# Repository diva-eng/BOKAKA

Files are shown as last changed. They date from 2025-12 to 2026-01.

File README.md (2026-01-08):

# Bokaka (ボカカ)

<div align="center">
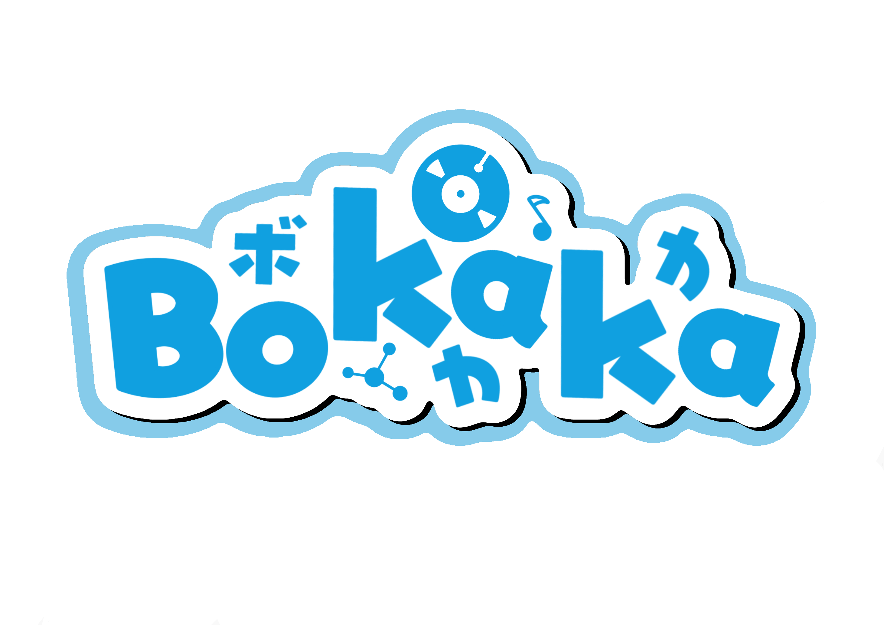
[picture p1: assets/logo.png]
Bokaka Logo
  
</div>

## Overview

Bokaka is an open-hardware, open-firmware credit-card–sized PCB distributed as a collectible at VOCALOID events (including Hatsune Miku concerts). Each unit contains a microcontroller, LEDs, a tap-to-connect interface, and local storage to record brief peer-to-peer interactions. The device visualizes interaction progress through onboard LEDs and supports synchronization with a companion website over USB.

## Key Capabilities

- Record unique, short-range interactions with other Bokaka units via a simple 1‑wire handshake over magnetic connectors.
- Persist interaction records in on‑board flash and present a visual progress/connection meter using 34 animation LEDs.
- Connect to a host computer over USB (WebUSB compatible) to claim the device, attach personal information, and upload interaction data to a companion website.
- Per-device security with unique device ID and locally stored HMAC-SHA256 secret keys.

## Hardware Summary

- Form factor: Credit-card–sized PCB
- Microcontroller: STM32L053R8 (low power, USB, unique device ID)
- Power:
  - Primary: CR2450 coin cell for sustained standalone operation
  - Optional: USB‑C for data and power
- Communication:
  - 2× 3-wire magnetic connectors with 1-wire open-drain Bokaka protocol
  - USB CDC (WebUSB compatible) for host connectivity
- Peripherals:
  - LED driver: IS31FL3236A (36-channel LED driver)
  - LEDs: 34 animation LEDs, 1 user status LED, 1 debug LED (36 total)
  - Single status button
  - Buzzer for simple sound feedback

## Functional Description

When two Bokaka units are tapped together via their magnetic connectors, they perform a one‑wire open-drain handshake and exchange unique identifiers. Each successful exchange is recorded to on‑board flash memory with CRC32 integrity checking. The device uses the IS31FL3236A LED driver to control 34 animation LEDs that display connection status, progress animations, and cumulative "connection meter" patterns. Two additional LEDs (user status and debug) provide system feedback. When connected to a host computer via USB, the user may:

1. Claim ownership of the card.
2. Attach optional personal metadata to the device.
3. Synchronize recorded interactions with a companion website to visualize social graphs (WebUSB compatible, no drivers required).

## Development and Firmware

- Firmware: PlatformIO with the Arduino framework targeting the STM32L053R8, with platform abstraction layer for future STM32CubeIDE migration.
- PCB design: KiCad (open hardware files included).
- Security: Per-device HMAC-SHA256 with rotating key versions, unique device IDs.
- Storage: Internal flash with EEPROM emulation, CRC32 integrity checking, optimized delayed writes for flash wear management.
- Goals: Maintain low power consumption for CR2450 coin‑cell operation, robust flash management for interaction logs, and a simple, extensible 1-wire protocol for tap interactions.

## Project Structure (typical)

- hardware/ — KiCad project files and manufacturing outputs
- firmware/ — PlatformIO project, source code, and build scripts
- docs/ — Design notes, protocol specification, and user documentation
- tools/ — Utility scripts for flashing, testing, and data conversion

## Usage

- Standalone: Power via CR2450 coin cell and perform tap interactions with other units via magnetic connectors.
- Host mode: Connect via USB‑C to a host (WebUSB compatible) to perform claiming, metadata attachment, and data synchronization.
- Interaction protocol: 1‑wire open-drain handshake using the magnetic connector interface; exchanged identifiers are stored locally with CRC32 verification.

## Contribution & Licensing

Contributions are welcome. See [CONTRIBUTING.md](CONTRIBUTING.md) for process and coding standards. Utility scripts (including the provisioning helper) live in `utils/` — see [utils/README.md](utils/README.md) for usage. The project is released under an open hardware / open source license (see LICENSE).

## Contacts & Resources

Refer to the repository for detailed build instructions, protocol documentation, and firmware API references.

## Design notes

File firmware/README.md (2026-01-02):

# Bokaka Firmware

**Bokaka** is an interactive smart PCB card designed to connect VOCALOID fans through simple, meaningful physical interactions.  
Powered by a low‑energy microcontroller and magnetic tap‑to‑link interface, Bokaka creates a shared experience that blends hardware, community, and creativity.

---

## 🌱 What is Bokaka?

Bokaka is a pocket‑sized device that allows fans to exchange identity tokens simply by tapping their cards together.  
Each successful interaction lights up part of an LED pattern on the card—forming leeks, Miku‑themed shapes, or rare animations as you meet more fans.

- Meet someone → Tap cards  
- Cards exchange secure IDs  
- Your LED pattern grows  
- Reach milestones → unlock animations  
- Sync to the website → view your connection graph

Bokaka turns fan encounters into a visual memory you can carry.

---

## ✨ Features

| Feature | Description |
|---|---|
| **🔵 Tap‑to‑Connect** | Magnetic pogo‑pin contact pads with stable one‑wire handshake protocol |
| **🟢 LED Status Display** | Energy‑efficient LEDs showing connection status and role |
| **🟣 WebUSB Support** | No drivers required - configure and sync directly in your browser |
| **🛡 Per‑Device Security** | Unique device ID with locally stored HMAC secret key |
| **🌐 Connection Graph** | Sync to companion site for worldwide fan visualization |

---

## 🧩 Technical Overview

| Component | Detail |
|---|---|
| MCU | STM32L053R8 with unique ID + low‑power modes |
| Interface | Magnetic pogo‑pin contact pads (1-wire open-drain) |
| Security | Per‑device HMAC-SHA256 with rotating key versions |
| Connectivity | USB CDC (WebUSB compatible) |
| Storage | Internal flash with CRC32 integrity checking |
| Framework | Arduino (via PlatformIO) with platform abstraction layer |

---

## 📁 Project Structure

```
firmware/
├── include/                    # Header files
│   ├── platform_*.h            # Platform abstraction interfaces
│   ├── storage.h               # Persistent storage interface
│   ├── tap_link.h              # Tap link protocol
│   ├── usb_serial.h            # USB command handler
│   └── status_display.h        # LED status display
├── src/                        # Source files
│   ├── main.cpp                # Main application
│   ├── platform_*_arduino.cpp  # Arduino platform implementations
│   ├── storage.cpp             # Storage implementation
│   ├── tap_link.cpp            # Tap link protocol
│   └── status_display.cpp      # LED status display
├── lib/                        # Libraries
│   └── crypto_config/          # mbedTLS configuration
├── docs/                       # Documentation
│   ├── FLASH_LIFETIME_ANALYSIS.md
│   ├── TAP_LINK_TIMING.md
│   ├── TAP_INTERFACE_WIRING.md
│   └── STATUS_DISPLAY.md
├── utils/                      # Utility scripts
│   ├── provision.py            # Key provisioning tool
│   └── serial_test.py          # Serial testing utility
├── platformio.ini              # Build configuration
└── PLATFORM_ABSTRACTION.md     # Platform abstraction documentation
```

---

## 🔧 Building

### Prerequisites

- [PlatformIO](https://platformio.org/) (VSCode extension or CLI)
- ST-Link programmer/debugger

### Build Commands

```bash
# Build for production
pio run -e nucleo_l053r8

# Build with test commands enabled
pio run -e dev

# Upload to device
pio run -e nucleo_l053r8 -t upload

# Monitor serial output
pio device monitor
```

### Build Environments

| Environment | Description |
|---|---|
| `nucleo_l053r8` | Production build |
| `dev` | Development build with `ENABLE_TEST_COMMANDS` |

---

## ⚠️ Flash Memory Wear Management

The firmware uses EEPROM emulation on STM32 flash memory. **Flash wear is a critical consideration:**

- **Flash Endurance**: STM32L0 flash has ~10,000 erase/write cycles per page
- **Write Strategy**: 
  - Regular operations use a 30-second delayed write to batch changes
  - Critical operations (like key provisioning) write immediately but occur rarely
  - Optimized partial writes for tap count and links (8-18 bytes vs 896 bytes)

**Lifetime Estimates** (for <100 links/event, multiple events/year):
- **Realistic case**: ~40 years at 10 events/year
- **Worst case**: ~10 years if writes aren't batched
- **With external flash**: 400+ years (recommended for production)

📊 **See [docs/FLASH_LIFETIME_ANALYSIS.md](docs/FLASH_LIFETIME_ANALYSIS.md) for detailed calculations.**

---

## 📖 Documentation

| Document | Description |
|---|---|
| [PLATFORM_ABSTRACTION.md](PLATFORM_ABSTRACTION.md) | Platform abstraction layer design and migration guide |
| [MIGRATION_PLAN.md](MIGRATION_PLAN.md) | Step-by-step STM32CubeIDE migration plan |
| [docs/REFACTORING_GUIDE.md](docs/REFACTORING_GUIDE.md) | Code refactoring opportunities for testability |
| [docs/TAP_LINK_TIMING.md](docs/TAP_LINK_TIMING.md) | Tap link protocol timing diagrams |
| [docs/TAP_INTERFACE_WIRING.md](docs/TAP_INTERFACE_WIRING.md) | Hardware wiring guide for two-board testing |
| [docs/STATUS_DISPLAY.md](docs/STATUS_DISPLAY.md) | LED status patterns and configuration |
| [docs/FLASH_LIFETIME_ANALYSIS.md](docs/FLASH_LIFETIME_ANALYSIS.md) | Flash wear analysis and recommendations |

---

## ❤️ Community

Bokaka is made for fans who want to share a moment of connection—whether at concerts, events, or anywhere creativity brings people together.

If you'd like to contribute, discuss features, or share ideas, feel free to open issues or PRs!

---

## 📄 License

MIT License

Copyright (c) 2025 Diva Engineering

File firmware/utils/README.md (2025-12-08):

```markdown
**Provision Script**: Brief usage

- **Purpose**: `provision.py` provisions a device over USB serial by sending `HELLO`, provisioning a generated 32-byte secret via `PROVISION_KEY`, validating via `SIGN_STATE`, and storing keys locally.

- **Run (PowerShell)**:

  ```powershell
  # Watch for new COM ports and provision automatically (interactive confirmation enabled)
  python .\utils\provision.py

  # Watch a specific port and provision whenever it appears
  python .\utils\provision.py --port COM3

  # Provision once and exit
  python .\utils\provision.py --port COM3 --once

  # Skip signature validation step (device will not be asked to sign state)
  python .\utils\provision.py --no-validate

  # Emulate a device locally (no hardware required)
  python .\utils\provision.py --emulate

  # Emulate with a longer artificial response delay so the UI updates are visible
  python .\utils\provision.py --emulate --emulate-delay 0.8

  # Skip interactive confirmation prompts (auto-accept provisioning)
  python .\utils\provision.py --emulate --no-confirm

  # Use a master key (hex) to derive device keys deterministically
  python .\utils\provision.py --master-key-hex ABCDEF0123...    # pass 32-byte master key as hex

  # Or load a PEM private key to sign provisioned secrets
  python .\utils\provision.py --master-key-pem path/to/key.pem
  ```

- **Dependencies**:
  - `pyserial` — install with `pip install pyserial`.
  - `rich` — optional but recommended for the improved in-place UI (Device / Status / Log panels, colored output, spinner and elapsed timer). Install with `pip install rich`.
  - `cryptography` — optional; required when using `--master-key-hex` or `--master-key-pem` to sign provisioned secrets. Install with `pip install cryptography`.

- **New / notable features**:
  - In-place UI (uses `rich` when available): separate Device / Status / Log panels, colored log output, auto-scroll to latest lines, and a small spinner + elapsed timer in the status bar.
  - Emulation improvements: `--emulate-delay` controls artificial response delay so UI updates are visible.
  - Interactive confirmation: the script prompts before provisioning a newly-detected device (shows device info from `HELLO`) and temporarily suspends the live UI to accept keyboard input.
  - Non-interactive mode: pass `--no-confirm` to skip confirmation prompts and accept provisioning automatically (useful for CI or batch runs).

- **Output**: keys are saved to `utils/provision_keys.json` by default; use `--out <path>` to change the file.

If you want me to add support for selecting VID/PID, filtering candidate ports, or changing colors/layout, I can extend the script.
```

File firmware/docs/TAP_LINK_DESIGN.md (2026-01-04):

# Tap Link Design

## Overview

TapLink implements device-to-device communication over a single GPIO wire using an open-drain protocol. It handles connection detection, role negotiation, and bidirectional command exchange.

## Operation Modes

### Eval Board Mode (EVAL_BOARD_TEST)

USB-powered continuous monitoring for development:
- Sends periodic presence pulses
- Automatic role negotiation on connection
- Command protocol for peer communication

### Battery Mode (default)

CR2032-powered with sleep/wake:
- MCU sleeps until tap wake-up interrupt
- Validates connection stability
- Minimal power consumption

## Architecture

```
┌─────────────────────────────────────────────────────────────┐
│                         Application                         │
├─────────────────────────────────────────────────────────────┤
│         ITapLink / ITapLinkEval / ITapLinkBattery           │
├─────────────────────────────────────────────────────────────┤
│                           TapLink                           │
│  ┌─────────────┐  ┌──────────────┐  ┌────────────────────┐  │
│  │ Detection   │  │ Negotiation  │  │ Command Protocol   │  │
│  │ State       │  │ (UID bits)   │  │ (Master/Slave)     │  │
│  └─────────────┘  └──────────────┘  └────────────────────┘  │
├─────────────────────────────────────────────────────────────┤
│                         IOneWireHal                         │
│                 (tap_link_hal_arduino.cpp)                  │
├─────────────────────────────────────────────────────────────┤
│                      Platform GPIO HAL                      │
└─────────────────────────────────────────────────────────────┘
```

## Electrical Interface

### Open-Drain Protocol

```
          Device A                    Device B
             │                           │
   ┌─────────┴─────────┐       ┌─────────┴─────────┐
   │ GPIO (Open-Drain) │───────│ GPIO (Open-Drain) │
   │ + Internal Pull-up│       │ + Internal Pull-up│
   └───────────────────┘       └───────────────────┘
```

- Idle state: HIGH (via internal pull-ups)
- Either device can pull LOW
- Wired-AND: line is HIGH only if both devices release
- No bus contention possible

### GPIO Configuration

| Mode | Config | Description |
|---|---|---|
| Release | INPUT_PULLUP | High-Z with pull-up (line goes HIGH) |
| Drive LOW | OUTPUT + LOW | Actively pulls line to ground |

## Detection State Machine (Eval Mode)

```
┌──────────────┐
│ NoConnection │◄────────────────────────────────┐
└──────┬───────┘                                 │
       │ Line goes LOW (peer pulse)              │
       ▼                                         │
┌──────────────┐                                 │
│  Detecting   │                                 │
└──────┬───────┘                                 │
       │ Line goes HIGH or debounce timeout      │
       ▼                                         │
┌──────────────┐                                 │
│ Negotiating  │                                 │
└──────┬───────┘                                 │
       │ Role determined                         │
       ▼                                         │
┌──────────────┐                                 │
│  Connected   │─────────────────────────────────┘
└──────────────┘   Timeout or repeated failures
```

## Presence Pulse Detection

When not connected, both devices send periodic presence pulses:

```
Timing:
- Pulse width: 2ms (PRESENCE_PULSE_US)
- Pulse interval: 50ms (PULSE_INTERVAL_US)
- Debounce time: 5ms (DEBOUNCE_TIME_US)

       Device A sends pulse                  Device B detects
              │                                    │
    HIGH ─────┴────┐          ┌────────────────────┴───────── HIGH
                   │          │
    LOW            └──────────┘
                   ◄──────────► 2ms
```

## Role Negotiation Protocol

### Synchronization Handshake

Both devices must start bit exchange simultaneously:

```
1. Release line, wait for HIGH
2. Send 10ms sync pulse
3. Wait for line HIGH
4. Wait for peer's sync pulse (up to 50ms)
5. Wait for peer's pulse to complete
6. 5ms delay
7. Send second 10ms sync pulse
8. Wait for line HIGH
9. 5ms final alignment delay
10. Begin bit exchange
```

This achieves ~1-2ms synchronization accuracy.

### UID Bit Exchange

Higher UID becomes Master. First 32 bits of device UID are compared:

```
Timing per bit:
- Drive period: 5ms (BIT_DRIVE_US)
- Sample point: 2.5ms (BIT_SAMPLE_US)
- Recovery: 2ms (BIT_RECOVERY_US)

For each bit position (MSB first):
1. Drive line based on my bit (0 = LOW, 1 = release)
2. Wait 2.5ms (sample point)
3. Sample line 3 times with majority voting
4. Continue driving until 5ms total
5. Release line
6. 2ms recovery
7. Next bit

Decision logic:
- If I sent '1' (released) but line is LOW → peer sent '0' → I am MASTER
- If bits match, continue to next bit
- After 32 bits: use random tie-breaker, then UID sum parity
```

### Why 5ms Drive Period

The long drive period (5ms) with mid-point sampling (2.5ms) ensures reliable reading even with ~2ms sync error between devices. Both devices are guaranteed to be in their drive phase when sampling occurs.

## Command Protocol (Connected State)

### Packet Format

```
START pulse (5ms) → Turnaround (2ms) → Command byte → Turnaround (2ms) → Response byte
```

### Bit Timing

Same as negotiation: 5ms drive, 2.5ms sample, 2ms recovery.

### Commands

| Code | Command | Description |
|---|---|---|
| 0x01 | CHECK_READY | Master polls slave availability |
| 0x02 | REQUEST_ID | Master requests slave's UID |
| 0x03 | SEND_ID | Master sends its UID to slave |

### Responses

| Code | Response | Description |
|---|---|---|
| 0x06 | ACK | Command successful |
| 0x15 | NAK | Command rejected |

### ID Exchange Sequence

```
Master                              Slave
  │                                   │
  ├── START + REQUEST_ID ───────────►│
  │                                   │
  │◄───────────── ACK ────────────────┤
  │◄──────────── UID (12 bytes) ──────┤
  │                                   │
  ├── START + SEND_ID ───────────────►│
  ├── UID (12 bytes) ────────────────►│
  │                                   │
  │◄───────────── ACK ────────────────┤
  │                                   │
```

### Disconnect Detection

**Master side:**
- Tracks consecutive command failures
- After 3 failures (MAX_COMMAND_FAILURES): transition to NoConnection
- Invalid responses (0xFF from floating line) count as failures

**Slave side:**
- Tracks time since last command received
- After 2 seconds (SLAVE_IDLE_TIMEOUT_US): transition to NoConnection

## Timing Constants

| Constant | Value | Purpose |
|---|---|---|
| DEBOUNCE_TIME_US | 5,000 | Connection detection debounce |
| PRESENCE_PULSE_US | 2,000 | Presence pulse width |
| PULSE_INTERVAL_US | 50,000 | Time between presence pulses |
| BIT_DRIVE_US | 5,000 | Bit drive duration |
| BIT_SAMPLE_US | 2,500 | Sample point within bit slot |
| BIT_RECOVERY_US | 2,000 | Recovery between bits |
| SYNC_PULSE_US | 10,000 | Sync handshake pulse |
| SYNC_WAIT_US | 5,000 | Sync alignment delay |
| CMD_START_PULSE_US | 5,000 | Command start pulse |
| CMD_TURNAROUND_US | 2,000 | Send/receive turnaround |
| CMD_TIMEOUT_US | 100,000 | Command response timeout |
| SLAVE_IDLE_TIMEOUT_US | 2,000,000 | Slave disconnect timeout |

## Battery Mode State Machine

```
┌──────────────┐
│   Sleeping   │◄────────────────┐
└──────┬───────┘                 │
       │ Wake-up interrupt       │
       ▼                         │
┌──────────────┐                 │
│    Waking    │─────────────────┤ Connection not stable
└──────┬───────┘                 │
       │ Validation complete     │
       ▼                         │
┌──────────────┐                 │
│  Connected   │                 │
└──────┬───────┘                 │
       │ Disconnect detected     │
       ▼                         │
┌──────────────┐                 │
│ Disconnected │─────────────────┘
└──────────────┘
```

### Connection Validation

Multiple line readings confirm stable connection:

```cpp
bool readings[5];
for (int i = 0; i < 5; i++) {
    readings[i] = _hal->readLine();
    delayMicros(100);
}
// Connection valid if all readings are consistent
```

## HAL Interface

```cpp
struct IOneWireHal {
    virtual bool readLine() = 0;              // true = HIGH
    virtual void driveLow(bool enable) = 0;   // true = pull LOW
    virtual uint32_t micros() = 0;
    virtual void delayMicros(uint32_t us) = 0;
};
```

Platform implementation in `tap_link_hal_arduino.cpp` maps to GPIO and timing HAL.

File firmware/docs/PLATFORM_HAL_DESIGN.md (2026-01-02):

# Platform Hardware Abstraction Layer Design

## Overview

The platform HAL provides hardware-independent interfaces for GPIO, timing, serial, storage, and device identification. This enables the same application code to run on Arduino/PlatformIO and STM32CubeIDE with minimal changes.

## Architecture

```
┌─────────────────────────────────────────────────────────────┐
│                      Application                             │
├─────────────────────────────────────────────────────────────┤
│                    Platform Interfaces                       │
│  ┌─────────┐ ┌─────────┐ ┌──────────┐ ┌─────────┐ ┌───────┐ │
│  │  GPIO   │ │ Timing  │ │ Serial   │ │ Storage │ │Device │ │
│  └────┬────┘ └────┬────┘ └────┬─────┘ └────┬────┘ └───┬───┘ │
├───────┼──────────┼──────────┼───────────┼──────────┼───────┤
│       │          │          │           │          │        │
│  ┌────┴────┐┌────┴────┐┌────┴─────┐┌────┴────┐┌────┴────┐  │
│  │ Arduino ││ Arduino ││ Arduino  ││ Arduino ││ Arduino │  │
│  │  GPIO   ││ millis  ││ Serial   ││ EEPROM  ││STM32 HAL│  │
│  └─────────┘└─────────┘└──────────┘└─────────┘└─────────┘  │
│                                                              │
│  ┌─────────┐┌─────────┐┌──────────┐┌─────────┐┌─────────┐  │
│  │STM32 HAL││STM32 HAL││ STM32 USB││STM32 HAL││STM32 HAL│  │
│  │  GPIO   ││  TIM    ││   CDC    ││ FLASH   ││  UID    │  │
│  └─────────┘└─────────┘└──────────┘└─────────┘└─────────┘  │
└─────────────────────────────────────────────────────────────┘
```

## GPIO Interface

**Header:** `include/platform_gpio.h`  
**Arduino impl:** `src/platform_gpio_arduino.cpp`

### Pin Modes

```cpp
typedef enum {
    PLATFORM_GPIO_MODE_INPUT,        // High-impedance input
    PLATFORM_GPIO_MODE_INPUT_PULLUP, // Input with internal pull-up
    PLATFORM_GPIO_MODE_OUTPUT,       // Push-pull output
    PLATFORM_GPIO_MODE_OUTPUT_OD     // Open-drain output
} platform_gpio_mode_t;
```

### Functions

```cpp
void platform_gpio_pin_mode(uint32_t pin, platform_gpio_mode_t mode);
bool platform_gpio_read(uint32_t pin);
void platform_gpio_write(uint32_t pin, platform_gpio_state_t state);
```

### Arduino Implementation Notes

- `PLATFORM_GPIO_MODE_OUTPUT_OD` maps to standard OUTPUT mode
- True open-drain behavior depends on hardware capability
- Pin identifiers use Arduino constants (PA5, PA6, etc.)

### STM32 HAL Migration

```cpp
// Arduino
pinMode(pin, INPUT_PULLUP);
digitalRead(pin);
digitalWrite(pin, HIGH);

// STM32 HAL
GPIO_InitTypeDef init = {.Mode = GPIO_MODE_INPUT, .Pull = GPIO_PULLUP};
HAL_GPIO_Init(GPIOx, &init);
HAL_GPIO_ReadPin(GPIOx, pin);
HAL_GPIO_WritePin(GPIOx, pin, GPIO_PIN_SET);
```

## Timing Interface

**Header:** `include/platform_timing.h`  
**Arduino impl:** `src/platform_timing_arduino.cpp`

### Functions

```cpp
void platform_timing_init();           // Initialize timing system
uint32_t platform_millis();            // Milliseconds since boot (wraps ~49 days)
uint32_t platform_micros();            // Microseconds since boot (wraps ~71 min)
void platform_delay_ms(uint32_t ms);   // Blocking millisecond delay
void platform_delay_us(uint32_t us);   // Blocking microsecond delay
```

### Arduino Implementation

Direct wrapper around Arduino functions:
- `millis()`, `micros()`, `delay()`, `delayMicroseconds()`
- `platform_timing_init()` is a no-op (Arduino auto-initializes)

### STM32 HAL Migration

```cpp
// Uses SysTick or dedicated timer
HAL_GetTick();           // 1ms resolution
TIM->CNT;                // Microsecond counter from hardware timer
HAL_Delay(ms);           // Blocking delay
// Custom DWT cycle counter for microsecond delays
```

### Overflow Handling

The application handles timer overflow correctly:

```cpp
uint32_t elapsedMicros(uint32_t startTime) {
    uint32_t now = platform_micros();
    if (now >= startTime) {
        return now - startTime;
    } else {
        return (UINT32_MAX - startTime) + now + 1;
    }
}
```

## Serial Interface

**Header:** `include/platform_serial.h`  
**Arduino impl:** `src/platform_serial_arduino.cpp`

### Functions

```cpp
void platform_serial_begin(uint32_t baud);   // Initialize (baud ignored for USB)
int platform_serial_available();             // Bytes available to read
int platform_serial_read();                  // Read byte (-1 if none)
void platform_serial_print(const char* str); // Print string
void platform_serial_print(int num);         // Print integer
void platform_serial_print(uint32_t num);    // Print unsigned
void platform_serial_print_hex(uint8_t byte);// Print hex byte
void platform_serial_println(const char* str);
void platform_serial_flush();                // Wait for TX complete
```

### Arduino Implementation

Direct wrapper around `Serial` object (USB CDC on STM32).

### STM32 HAL Migration

```cpp
// USB CDC requires CDC_Transmit_FS() and CDC_Receive_FS()
// Or UART with HAL_UART_Transmit/Receive
CDC_Transmit_FS((uint8_t*)str, strlen(str));
```

## Storage Interface

**Header:** `include/platform_storage.h`  
**Arduino impl:** `src/platform_storage_arduino.cpp`

### Functions

```cpp
bool platform_storage_begin(size_t size);      // Initialize storage
uint8_t platform_storage_read(size_t address); // Read byte
void platform_storage_write(size_t address, uint8_t value);
bool platform_storage_commit();                // Flush writes
```

### Arduino Implementation Notes

- Uses STM32 Arduino EEPROM library
- `EEPROM.begin()` doesn't take size parameter on STM32
- Size is tracked internally for bounds checking
- `commit()` may be no-op depending on core implementation

### STM32 HAL Migration

EEPROM emulation in flash requires:
- Page erase before write
- Virtual address mapping
- Wear leveling (optional)

```cpp
// STM32 HAL flash operations
HAL_FLASHEx_DATAEEPROM_Unlock();
HAL_FLASHEx_DATAEEPROM_Program(FLASH_TYPEPROGRAMDATA_BYTE, addr, data);
HAL_FLASHEx_DATAEEPROM_Lock();
```

## Device Identity Interface

**Header:** `include/platform_device.h`  
**Arduino impl:** `src/platform_device_arduino.cpp`

### Functions

```cpp
void platform_get_device_uid(uint8_t out[PLATFORM_DEVICE_UID_SIZE]);
```

Returns 12-byte (96-bit) unique device ID.

### STM32 Implementation

STM32L0 UID is stored at fixed memory addresses, accessible via HAL:

```cpp
uint32_t w0 = HAL_GetUIDw0();
uint32_t w1 = HAL_GetUIDw1();
uint32_t w2 = HAL_GetUIDw2();
```

Bytes are extracted in big-endian order for consistent ID comparison across devices.

### Memory Layout

```
UID Word 0 (address 0x1FF80050): out[0..3]
UID Word 1 (address 0x1FF80054): out[4..7]
UID Word 2 (address 0x1FF80064): out[8..11]
```

## TapLink HAL

**Header:** `include/tap_link_hal.h`  
**Arduino impl:** `src/tap_link_hal_arduino.cpp`

### Interface

```cpp
struct IOneWireHal {
    virtual bool readLine() = 0;              // Read physical line state
    virtual void driveLow(bool enableLow) = 0;// Control line driver
    virtual uint32_t micros() = 0;            // Get microseconds
    virtual void delayMicros(uint32_t us) = 0;// Blocking delay
};
```

### Arduino Implementation

```cpp
class OneWireHalArduino : public IOneWireHal {
    uint32_t _pin;
public:
    bool readLine() override {
        return platform_gpio_read(_pin);
    }
    
    void driveLow(bool enableLow) override {
        if (enableLow) {
            platform_gpio_pin_mode(_pin, PLATFORM_GPIO_MODE_OUTPUT);
            platform_gpio_write(_pin, PLATFORM_GPIO_LOW);
        } else {
            platform_gpio_pin_mode(_pin, PLATFORM_GPIO_MODE_INPUT_PULLUP);
        }
    }
    
    uint32_t micros() override { return platform_micros(); }
    void delayMicros(uint32_t us) override { platform_delay_us(us); }
};
```

## Board Configuration

**Header:** `include/board_config.h`

Pin definitions with defaults, overridable via build flags:

```cpp
#ifndef STATUS_LED0_PIN
#define STATUS_LED0_PIN PA5   // D13 on Nucleo
#endif

#ifndef STATUS_LED1_PIN
#define STATUS_LED1_PIN PA6   // D12 on Nucleo
#endif

#ifndef TAP_LINK_PIN
#define TAP_LINK_PIN PA9      // D8 on Nucleo
#endif
```

Override in `platformio.ini`:
```ini
build_flags = -DSTATUS_LED0_PIN=PB0
```

## Migration Checklist

To port to STM32CubeIDE:

1. **GPIO:** Replace pinMode/digitalRead/Write with HAL_GPIO_*
2. **Timing:** Configure SysTick, add microsecond timer
3. **Serial:** Implement USB CDC or UART wrapper
4. **Storage:** Implement flash EEPROM emulation
5. **Device:** Direct memory access for UID (already uses HAL)
6. **Sleep:** Add HAL_PWR_EnterSLEEPMode with GPIO wake-up

See `PLATFORM_ABSTRACTION.md` and `MIGRATION_PLAN.md` for detailed migration steps.

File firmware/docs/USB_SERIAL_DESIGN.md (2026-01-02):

# USB Serial Command Handler Design

## Overview

The USB serial module provides a JSON-based command interface over USB CDC for device management, debugging, and provisioning.

## Architecture

```
┌─────────────────────────────────────────────────────────────┐
│                    Host PC (Python/etc)                      │
├─────────────────────────────────────────────────────────────┤
│                      USB CDC Serial                          │
├─────────────────────────────────────────────────────────────┤
│                  UsbCommandHandler                           │
│  ┌─────────────┐  ┌──────────────┐  ┌────────────────────┐  │
│  │ Line Buffer │  │ Command Parse│  │ JSON Response      │  │
│  └─────────────┘  └──────────────┘  └────────────────────┘  │
├─────────────────────────────────────────────────────────────┤
│                  Platform Serial HAL                         │
│              (platform_serial_arduino.cpp)                   │
├─────────────────────────────────────────────────────────────┤
│                   Arduino Serial (USB CDC)                   │
└─────────────────────────────────────────────────────────────┘
```

## Initialization

### USB CDC Enumeration

STM32 USB CDC requires time to enumerate after power-on:

```cpp
void begin(unsigned long baud) {
    platform_serial_begin(baud);
    platform_delay_ms(500);        // Wait for USB enumeration
    
    // Flush stale data from input buffer
    uint32_t flushStart = platform_millis();
    while (platform_serial_available() > 0 && 
           (platform_millis() - flushStart < 100)) {
        platform_serial_read();
        platform_delay_ms(1);
    }
    
    platform_delay_ms(100);        // Final settling time
}
```

Without this flush, the first command can be corrupted by initialization noise.

## Command Protocol

### Line Format

- Commands are newline-terminated (`\n` or `\r\n`)
- Case-insensitive (converted to uppercase internally)
- Arguments separated by spaces

### Response Format

All responses are JSON objects with an `event` field:

```json
{"event":"hello","device_id":"...","fw":"1.0.0"}
{"event":"state","totalTapCount":42,"linkCount":5}
{"event":"error","msg":"unknown command: FOO"}
```

## Commands

### HELLO

Returns device identification and firmware info.

```
Request:  HELLO
Response: {"event":"hello","device_id":"<24-char hex>","fw":"1.0.0","build":"2026-01-03T12:00:00Z","hash":"abc123"}
```

### GET_STATE

Returns current tap statistics.

```
Request:  GET_STATE
Response: {"event":"state","totalTapCount":42,"linkCount":5}
```

### CLEAR / RESET_TAPS

Clears all links and tap count (preserves selfId and secret key).

```
Request:  CLEAR
Response: {"event":"ack","cmd":"CLEAR"}
```

Note: ACK is sent before the blocking EEPROM write to prevent serial timeout.

### DUMP [offset] [count]

Returns stored peer links with pagination.

```
Request:  DUMP 0 10
Response: {"event":"links","offset":0,"count":3,"items":[{"peer":"A1B2C3..."},{"peer":"D4E5F6..."}]}
```

Default: offset=0, count=10

### PROVISION_KEY version key_hex

Provisions a 32-byte secret key for HMAC signing.

```
Request:  PROVISION_KEY 1 <64-char hex key>
Response: {"event":"ack","cmd":"PROVISION_KEY","keyVersion":1}
```

Note: ACK sent before EEPROM write. Key is saved immediately (no delay).

### SIGN_STATE nonce_hex

Signs current state with HMAC-SHA256 for server verification.

```
Request:  SIGN_STATE <2-64 char hex nonce>
Response: {"event":"SIGNED_STATE","device_id":"...","nonce":"...","totalTapCount":42,"linkCount":5,"keyVersion":1,"hmac":"<64-char hex>"}
```

HMAC message structure:
```
selfId (12 bytes) + nonce (N bytes) + totalTapCount (4 LE) + linkCount (2 LE) + [peerId × linkCount]
```

### GET_KEY (test builds only)

Returns the stored secret key. Only available when `ENABLE_TEST_COMMANDS` is defined.

```
Request:  GET_KEY
Response: {"event":"key","keyVersion":1,"key":"<64-char hex>"}
```

## Input Processing

### Line Buffer

```cpp
static constexpr size_t CMD_BUF_SIZE = 128;
char _buf[CMD_BUF_SIZE];
size_t _len = 0;
```

Characters are accumulated until newline. Buffer overflow discards the line.

### Polling Model

```cpp
void poll(IStorage& storage) {
    while (platform_serial_available() > 0) {
        int c = platform_serial_read();
        if (c == '\r') continue;      // Ignore CR
        if (c == '\n') {
            _buf[_len] = '\0';
            handleLine(storage, _buf);
            _len = 0;
        } else {
            if (_len < CMD_BUF_SIZE - 1) {
                _buf[_len++] = c;
            } else {
                _len = 0;             // Overflow: discard
            }
        }
    }
}
```

## Utility Functions

### Hex Conversion

```cpp
bool hexToBytes(const char* hex, uint8_t* out, size_t outLen);
void bytesToHex(const uint8_t* in, size_t len, char* out);
void printHex(const uint8_t* data, size_t len);
```

Used for key provisioning, device ID display, and HMAC output.

## Error Handling

Errors return JSON with descriptive messages:

```json
{"event":"error","msg":"invalid key hex"}
{"event":"error","msg":"no_key"}
{"event":"error","msg":"PROVISION_KEY args"}
```

## Threading Considerations

- All operations are blocking
- Long EEPROM writes (CLEAR, PROVISION_KEY) send ACK first
- Polling model works with cooperative multitasking in `loop()`

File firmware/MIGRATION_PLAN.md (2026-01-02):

# Migration Plan: PlatformIO → STM32CubeIDE

## Overview

This document outlines the migration plan for moving the Bokaka firmware from PlatformIO/Arduino to STM32CubeIDE/HAL.

**Target:** STM32L053R8  
**Status:** ✅ Platform abstraction complete - ready for HAL implementation

---

## Current Architecture

All application code is **platform-independent**. Only the platform implementation files need to be replaced:

| Layer | Status | Notes |
|---|---|---|
| Application (`main.cpp`, `storage.cpp`, `usb_serial.cpp`, `tap_link.cpp`) | ✅ Abstracted | No changes needed |
| Platform interfaces (`platform_*.h`) | ✅ Complete | Define the abstraction API |
| Arduino implementations (`*_arduino.cpp`) | ✅ Working | Current PlatformIO build |
| HAL implementations (`*_hal.cpp`) | 🔄 To create | For STM32CubeIDE migration |

---

## Migration Steps

### Phase 1: STM32CubeIDE Project Setup

1. **Create new STM32 project** (STM32L053R8)
2. **Configure with CubeMX:**
   - System clock: HSI16 (16 MHz)
   - USB Device: CDC (Virtual COM Port)
   - GPIO: PA9 for tap link, PA5/PA6 for status LEDs
3. **Generate code**

### Phase 2: Copy Application Code

Copy to `Core/Inc/` and `Core/Src/`:

```
Headers (include/ → Core/Inc/):
  storage.h, usb_serial.h, tap_link.h, tap_link_hal.h
  device_id.h, status_display.h, fw_config.h
  platform_timing.h, platform_serial.h
  platform_storage.h, platform_gpio.h

Sources (src/ → Core/Src/):
  storage.cpp, usb_serial.cpp, tap_link.cpp
  device_id.cpp, status_display.cpp
```

### Phase 3: Create HAL Implementations

Create these files (see [PLATFORM_ABSTRACTION.md](PLATFORM_ABSTRACTION.md) for implementation details):

| File | Purpose |
|---|---|
| `platform_timing_hal.cpp` | HAL timing (SysTick, DWT) |
| `platform_serial_hal.cpp` | USB CDC communication |
| `platform_storage_hal.cpp` | EEPROM emulation |
| `platform_gpio_hal.cpp` | GPIO operations |
| `tap_link_hal_hal.cpp` | Tap link HAL (copy from Arduino, update pins) |

### Phase 4: Convert Main Entry Point

Replace Arduino `setup()`/`loop()` with standard `main()`:

```cpp
int main(void) {
    HAL_Init();
    SystemClock_Config();
    MX_GPIO_Init();
    MX_USB_DEVICE_Init();
    
    platform_timing_init();
    // ... existing setup code (unchanged!) ...
    
    while (1) {
        // ... existing loop code (unchanged!) ...
    }
}
```

### Phase 5: Integrate mbedTLS

1. Download mbedTLS 2.23.0+
2. Copy to `Middlewares/mbedTLS/`
3. Copy `lib/crypto_config/mbedtls_config.h`
4. Configure build:
   - Add include paths
   - Add define: `MBEDTLS_CONFIG_FILE="mbedtls_config.h"`

### Phase 6: Build & Test

1. Enable C++ support in project settings
2. Fix compilation errors
3. Test all functionality

---

## HAL Implementation Notes

### Timing

```cpp
void platform_timing_init() {
    CoreDebug->DEMCR |= CoreDebug_DEMCR_TRCENA_Msk;
    DWT->CTRL |= DWT_CTRL_CYCCNTENA_Msk;
}

uint32_t platform_millis() { return HAL_GetTick(); }
uint32_t platform_micros() { return DWT->CYCCNT / (SystemCoreClock / 1000000); }
void platform_delay_ms(uint32_t ms) { HAL_Delay(ms); }
```

### USB Serial

Use CubeMX-generated `usbd_cdc_if.c` functions:
- `CDC_Transmit()` for output
- `CDC_Receive()` for input

### Storage

Use STM32 EEPROM Emulation library from STM32CubeL0:
- `EE_Init()` for initialization
- `EE_ReadVariable()` / `EE_WriteVariable()` for read/write
- Handle 16-bit word alignment

### GPIO

```cpp
void platform_gpio_pin_mode(uint32_t pin, platform_gpio_mode_t mode) {
    GPIO_InitTypeDef init = {0};
    init.Pin = get_gpio_pin(pin);
    init.Mode = (mode == PLATFORM_GPIO_MODE_OUTPUT) ? GPIO_MODE_OUTPUT_PP : GPIO_MODE_INPUT;
    init.Pull = (mode == PLATFORM_GPIO_MODE_INPUT_PULLUP) ? GPIO_PULLUP : GPIO_NOPULL;
    HAL_GPIO_Init(get_gpio_port(pin), &init);
}
```

---

## Testing Checklist

### Hardware Tests

- [ ] GPIO (tap link) - read/write, open-drain
- [ ] GPIO (status LEDs) - LED patterns
- [ ] USB CDC - connect, enumerate, communicate
- [ ] Flash storage - read/write, power cycle
- [ ] Device UID - read correctly
- [ ] Timing - millis, micros, delays accurate

### Functional Tests

- [ ] Storage: begin(), saveNow(), clearAll(), addLink()
- [ ] USB commands: hello, get_state, clear, dump
- [ ] USB commands: provision_key, sign_state
- [ ] Tap link: connection protocol, state machine
- [ ] Status display: LED patterns for each state
- [ ] Crypto: HMAC-SHA256 signing

### Comparison Tests

- [ ] Command responses match PlatformIO version
- [ ] Timing behavior matches
- [ ] Performance similar or better

---

## Timeline Estimate

| Phase | Duration |
|---|---|
| Project Setup | 2-4 hours |
| Core Migration | 8-12 hours |
| Storage Migration | 4-6 hours |
| mbedTLS Integration | 2-4 hours |
| Build System | 2-3 hours |
| Testing & Debugging | 8-16 hours |
| **Total** | **26-45 hours** |

---

## Risk Mitigation

| Risk | Mitigation |
|---|---|
| USB CDC buffer issues | Implement ring buffers, test thoroughly |
| Flash wear | Use ST EEPROM emulation, monitor cycles |
| Timing accuracy | Use DWT counter, verify with scope |
| GPIO behavior | Test open-drain, verify pull-up/down |
| mbedTLS config | Start minimal, test incrementally |

---

## Resources

- [STM32L0 HAL Documentation](https://www.st.com/resource/en/user_manual/um1884-description-of-stm32l0-hal-and-lowlayer-drivers-stmicroelectronics.pdf)
- [STM32CubeL0 Examples](https://www.st.com/en/embedded-software/stm32cubel0.html)
- [mbedTLS Documentation](https://mbed-tls.readthedocs.io/)

---

*Last Updated: January 2026*

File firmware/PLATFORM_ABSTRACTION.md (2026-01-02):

# Platform Abstraction Layer

This document describes the platform abstraction layer that enables easy migration between Arduino/PlatformIO and STM32CubeIDE/HAL.

---

## Overview

The abstraction layer provides platform-independent interfaces for:

| Module | Header | Description |
|---|---|---|
| **Timing** | `platform_timing.h` | millis, micros, delays |
| **Serial** | `platform_serial.h` | USB CDC communication |
| **Storage** | `platform_storage.h` | EEPROM read/write |
| **GPIO** | `platform_gpio.h` | Pin mode, read, write |

---

## Current Implementation

### Arduino (Working)

| Header | Implementation |
|---|---|
| `platform_timing.h` | `platform_timing_arduino.cpp` |
| `platform_serial.h` | `platform_serial_arduino.cpp` |
| `platform_storage.h` | `platform_storage_arduino.cpp` |
| `platform_gpio.h` | `platform_gpio_arduino.cpp` |

### STM32 HAL (For Migration)

Create these files when migrating to STM32CubeIDE:

| Header | Implementation |
|---|---|
| `platform_timing.h` | `platform_timing_hal.cpp` |
| `platform_serial.h` | `platform_serial_hal.cpp` |
| `platform_storage.h` | `platform_storage_hal.cpp` |
| `platform_gpio.h` | `platform_gpio_hal.cpp` |

---

## Quick Reference API

### Timing Functions

```cpp
#include "platform_timing.h"

platform_timing_init();              // Call once at startup

uint32_t ms = platform_millis();     // Milliseconds since startup
uint32_t us = platform_micros();     // Microseconds since startup

platform_delay_ms(100);              // Delay 100 milliseconds
platform_delay_us(50);               // Delay 50 microseconds
```

### Serial/USB Communication

```cpp
#include "platform_serial.h"

platform_serial_begin(115200);       // Initialize (baud ignored for USB CDC)

int avail = platform_serial_available();  // Check available bytes
int byte = platform_serial_read();        // Read byte (-1 if none)

platform_serial_print("Hello");      // Print string
platform_serial_println("World");    // Print with newline
platform_serial_print(42);           // Print integer
platform_serial_print((uint32_t)n);  // Print unsigned
platform_serial_print_hex(0xAB);     // Print "AB"
platform_serial_flush();             // Wait for transmission
```

### Storage/EEPROM

```cpp
#include "platform_storage.h"

platform_storage_begin(2048);        // Initialize storage (size in bytes)

uint8_t val = platform_storage_read(addr);    // Read byte
platform_storage_write(addr, 0x42);           // Write byte
platform_storage_commit();                    // Persist writes
```

### GPIO Operations

```cpp
#include "platform_gpio.h"

// Configure pin mode
platform_gpio_pin_mode(pin, PLATFORM_GPIO_MODE_INPUT);
platform_gpio_pin_mode(pin, PLATFORM_GPIO_MODE_INPUT_PULLUP);
platform_gpio_pin_mode(pin, PLATFORM_GPIO_MODE_OUTPUT);
platform_gpio_pin_mode(pin, PLATFORM_GPIO_MODE_OUTPUT_OD);  // Open-drain

// Read/Write
bool state = platform_gpio_read(pin);  // Returns true if HIGH
platform_gpio_write(pin, PLATFORM_GPIO_HIGH);
platform_gpio_write(pin, PLATFORM_GPIO_LOW);
```

---

## Migration Guide

### Step 1: Create HAL Implementations

Copy Arduino implementations as templates and replace with HAL equivalents:

#### Timing (`platform_timing_hal.cpp`)

```cpp
#include "platform_timing.h"
#include "stm32l0xx_hal.h"

void platform_timing_init() {
    // HAL_Init() already called by main()
    // Enable DWT for microsecond timing
    CoreDebug->DEMCR |= CoreDebug_DEMCR_TRCENA_Msk;
    DWT->CTRL |= DWT_CTRL_CYCCNTENA_Msk;
}

uint32_t platform_millis() {
    return HAL_GetTick();
}

uint32_t platform_micros() {
    return DWT->CYCCNT / (SystemCoreClock / 1000000);
}

void platform_delay_ms(uint32_t ms) {
    HAL_Delay(ms);
}

void platform_delay_us(uint32_t us) {
    uint32_t start = platform_micros();
    while (platform_micros() - start < us);
}
```

#### Serial (`platform_serial_hal.cpp`)

```cpp
#include "platform_serial.h"
#include "usbd_cdc_if.h"
#include <stdio.h>

void platform_serial_begin(uint32_t baud) {
    // USB CDC doesn't use baud rate
    while (!CDC_IsConnected()) HAL_Delay(10);
}

int platform_serial_available() {
    return CDC_GetRxBufferLen();
}

int platform_serial_read() {
    uint8_t buf;
    return (CDC_Receive(&buf, 1) > 0) ? buf : -1;
}

void platform_serial_print(const char* str) {
    CDC_Transmit((uint8_t*)str, strlen(str));
}
// ... implement remaining functions
```

#### Storage (`platform_storage_hal.cpp`)

Use STM32 EEPROM emulation library from STM32CubeL0.

#### GPIO (`platform_gpio_hal.cpp`)

```cpp
#include "platform_gpio.h"
#include "stm32l0xx_hal.h"

void platform_gpio_pin_mode(uint32_t pin, platform_gpio_mode_t mode) {
    GPIO_InitTypeDef init = {0};
    init.Pin = get_gpio_pin(pin);
    
    switch (mode) {
        case PLATFORM_GPIO_MODE_INPUT:
            init.Mode = GPIO_MODE_INPUT;
            init.Pull = GPIO_NOPULL;
            break;
        case PLATFORM_GPIO_MODE_INPUT_PULLUP:
            init.Mode = GPIO_MODE_INPUT;
            init.Pull = GPIO_PULLUP;
            break;
        case PLATFORM_GPIO_MODE_OUTPUT:
            init.Mode = GPIO_MODE_OUTPUT_PP;
            break;
        case PLATFORM_GPIO_MODE_OUTPUT_OD:
            init.Mode = GPIO_MODE_OUTPUT_OD;
            break;
    }
    HAL_GPIO_Init(get_gpio_port(pin), &init);
}
```

### Step 2: Update Build System

- Add HAL implementation files to project
- Remove/exclude Arduino implementation files
- Configure include paths

### Step 3: Convert Main Entry Point

Replace `setup()`/`loop()` with `main()`:

```cpp
int main(void) {
    HAL_Init();
    SystemClock_Config();
    MX_GPIO_Init();
    MX_USB_DEVICE_Init();
    
    platform_timing_init();
    // ... existing setup code (unchanged!) ...
    
    while (1) {
        // ... existing loop code (unchanged!) ...
    }
}
```

---

## Function Replacement Reference

| Arduino | STM32 HAL | Notes |
|---|---|---|
| `millis()` | `HAL_GetTick()` | Requires SysTick |
| `micros()` | DWT cycle counter | Enable DWT in init |
| `delay(ms)` | `HAL_Delay(ms)` | Blocking |
| `delayMicroseconds(us)` | Custom DWT | Busy wait |
| `pinMode(pin, mode)` | `HAL_GPIO_Init()` | Configure struct |
| `digitalRead(pin)` | `HAL_GPIO_ReadPin()` | Returns SET/RESET |
| `digitalWrite(pin, val)` | `HAL_GPIO_WritePin()` | Use SET/RESET |
| `Serial.begin()` | USB CDC init | Wait for connection |
| `Serial.available()` | `CDC_GetRxBufferLen()` | Check buffer |
| `Serial.read()` | `CDC_Receive()` | From USB buffer |
| `Serial.print()` | `CDC_Transmit()` | Non-blocking |
| `EEPROM.begin()` | `EE_Init()` | EEPROM emulation |
| `EEPROM.read()` | `EE_ReadVariable()` | 16-bit words |
| `EEPROM.write()` | `EE_WriteVariable()` | 16-bit words |

---

## Benefits

1. **Zero Application Code Changes**: All application logic uses abstractions
2. **Easy Migration**: Just swap implementation files
3. **Testability**: Test Arduino version while developing HAL version
4. **Maintainability**: Clear separation between platform and application

---

## File Structure

```
firmware/
├── include/
│   ├── platform_timing.h
│   ├── platform_serial.h
│   ├── platform_storage.h
│   └── platform_gpio.h
└── src/
    ├── platform_timing_arduino.cpp   # Arduino (current)
    ├── platform_serial_arduino.cpp
    ├── platform_storage_arduino.cpp
    ├── platform_gpio_arduino.cpp
    ├── platform_timing_hal.cpp       # HAL (create for migration)
    ├── platform_serial_hal.cpp
    ├── platform_storage_hal.cpp
    └── platform_gpio_hal.cpp
```

---

*Last Updated: January 2026*

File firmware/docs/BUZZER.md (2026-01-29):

# Buzzer Documentation

## Overview

The `Buzzer` class provides audio feedback for the Bokaka firmware using a passive piezo buzzer (HS-F02A or similar). It uses the platform abstraction layer (`platform_buzzer.h`) for PWM tone generation, enabling easy migration between Arduino and STM32 HAL.

## Features

- **Platform-Independent**: Uses PWM abstraction for tone generation
- **Non-Blocking**: Melody playback handled in main loop
- **Multi-Note Melodies**: Supports sequences with pauses between notes
- **Scheduled Tones**: Delay tone playback for fast events
- **Configurable Pin**: Override via build flags

---

## Hardware

### HS-F02A Passive Piezo Buzzer

| Specification | Value |
|---|---|
| Type | Passive (requires PWM) |
| Resonant Frequency | ~2700 Hz |
| Effective Range | 2000–4000 Hz |
| Operating Voltage | 3.3V–5V |
| Current | ~30mA max |

### Wiring (NUCLEO-L053R8)

| Buzzer Pin | Board Pin | Arduino Name | STM32 Pin |
|---|---|---|---|
| + (Signal) | D9 | PC7 | PC7 (TIM3_CH2 / TIM22_CH2) |
| − (Ground) | GND | GND | GND |

> **Note**: D9 on NUCLEO-L053R8 is PWM-capable via TIM3 or TIM22.

---

## Feedback Tones

### Tone Events

| Event | Tone | Description |
|---|---|---|
| **Detection** | Short beep | Plays when devices first touch |
| **Success** | Ascending arpeggio | Plays after successful ID exchange |
| **Error** | Descending tone | Plays on communication error |
| **Confirm** | Single beep | General confirmation |

### Tone Specifications

| Tone | Frequencies | Durations | Total Time |
|---|---|---|---|
| Detection | 2700 Hz | 50ms | ~50ms |
| Success | 2000 → 2700 → 3500 Hz | 50ms + 30ms pause each | ~240ms |
| Error | 2700 → 2000 Hz | 100ms + 50ms, 200ms | ~350ms |
| Confirm | 3200 Hz | 100ms | ~100ms |

### Timing Diagram

```
Detection Tone:
    ┌──────┐
    │ 2700 │
────┘      └────────────────────────────────────

Success Melody (with 150ms delay after ID exchange):
              ┌────┐   ┌────┐   ┌──────┐
              │2000│   │2700│   │ 3500 │
──────────────┘    └───┘    └───┘      └────────
   150ms delay   50ms 30ms 50ms 30ms  100ms
```

---

## API Reference

### Initialization

```cpp
#include "buzzer.h"

Buzzer buzzer;

void setup() {
    buzzer.begin(BUZZER_PIN);  // PC7 (D9) by default
}
```

### Main Loop

```cpp
void loop() {
    buzzer.loop();  // Must call to update melody playback
}
```

### Playing Tones

```cpp
// Predefined feedback tones
buzzer.playDetectionTone();   // Short beep on detection
buzzer.playSuccessTone();     // Ascending melody
buzzer.playErrorTone();       // Descending melody
buzzer.playConfirmTone();     // Single confirmation beep

// Scheduled tone (plays after delay)
buzzer.scheduleSuccessTone(150);  // Play success tone after 150ms

// Low-level control
buzzer.playTone(2700, 100);   // 2700 Hz for 100ms
buzzer.stop();                // Stop any playing tone
```

### State Queries

```cpp
if (buzzer.isPlaying()) {
    // Buzzer is currently active
}
```

---

## Integration Example

### With Tap Link Events

```cpp
void loop() {
    tapLink.poll();
    
    // Play detection tone when devices touch
    if (tapLink.isConnectionDetected()) {
        buzzer.playDetectionTone();
    }
    
    // Schedule success tone after ID exchange
    // (delayed because exchange happens quickly)
    if (idExchangeComplete) {
        buzzer.scheduleSuccessTone(150);
    }
    
    buzzer.loop();  // Update buzzer state
}
```

---

## Configuration

### Pin Configuration

Default pin is defined in `board_config.h`:

```cpp
#ifndef BUZZER_PIN
#ifdef PC7
#define BUZZER_PIN PC7        // Arduino: PC7 (D9) - PWM capable
#else
#define BUZZER_PIN 9          // Generic: GPIO 9
#endif
#endif
```

Override via build flags in `platformio.ini`:

```ini
build_flags =
    -DBUZZER_PIN=PA0
```

### Frequency Constants

Defined in `buzzer.h`:

```cpp
static constexpr uint32_t FREQ_LOW     = 2000;   // Low tone
static constexpr uint32_t FREQ_MID     = 2700;   // Mid tone (resonant)
static constexpr uint32_t FREQ_HIGH    = 3500;   // High tone
static constexpr uint32_t FREQ_CONFIRM = 3200;   // Confirmation tone
```

### Duration Constants

```cpp
static constexpr uint32_t DUR_SHORT    = 50;     // Short beep
static constexpr uint32_t DUR_MEDIUM   = 100;    // Medium beep
static constexpr uint32_t DUR_LONG     = 200;    // Long beep
```

---

## Platform Abstraction

### Arduino Implementation

The Arduino implementation (`platform_buzzer_arduino.cpp`) uses the built-in `tone()` and `noTone()` functions:

```cpp
void platform_buzzer_tone(uint32_t frequencyHz) {
    tone(g_buzzerPin, frequencyHz);
}

void platform_buzzer_stop() {
    noTone(g_buzzerPin);
}
```

### STM32 HAL Migration

For STM32CubeIDE, implement `platform_buzzer_hal.c` using timer PWM:

```c
// Example using TIM3 CH2 on PC7
void platform_buzzer_init(uint32_t pin) {
    // Configure TIM3 for PWM output on CH2
    HAL_TIM_PWM_Start(&htim3, TIM_CHANNEL_2);
}

void platform_buzzer_tone(uint32_t frequencyHz) {
    uint32_t period = SystemCoreClock / frequencyHz;
    __HAL_TIM_SET_AUTORELOAD(&htim3, period - 1);
    __HAL_TIM_SET_COMPARE(&htim3, TIM_CHANNEL_2, period / 2);  // 50% duty
}

void platform_buzzer_stop() {
    __HAL_TIM_SET_COMPARE(&htim3, TIM_CHANNEL_2, 0);
}
```

---

## Extending

### Adding a New Melody

1. Define notes in `buzzer.cpp`:

```cpp
const Buzzer::Note Buzzer::MELODY_CUSTOM[] = {
    { 3000, 80, 20 },   // 3000 Hz for 80ms, 20ms pause
    { 2500, 80, 20 },   // 2500 Hz for 80ms, 20ms pause
    { 2000, 150, 0 }    // 2000 Hz for 150ms, end
};
static constexpr uint8_t MELODY_CUSTOM_LEN = 3;
```

2. Add method in `buzzer.h`:

```cpp
void playCustomTone();
```

3. Implement in `buzzer.cpp`:

```cpp
void Buzzer::playCustomTone() {
    if (!_initialized) return;
    startMelody(MELODY_CUSTOM, MELODY_CUSTOM_LEN);
}
```

---

## Troubleshooting

| Issue | Check |
|---|---|
| No sound | Verify `begin()` called with correct pin |
| Buzzer always on | Ensure `loop()` is called in main loop |
| Wrong frequency | Check if buzzer is passive (active buzzers ignore frequency) |
| Melody cuts off | Verify `loop()` polling rate is fast enough (<10ms) |
| Scheduled tone not playing | Confirm `loop()` is called after scheduling |

---

## File Structure

```
include/
├── platform_buzzer.h      # Platform abstraction interface
├── buzzer.h               # High-level Buzzer class
└── board_config.h         # Pin definitions (BUZZER_PIN)

src/
├── platform_buzzer_arduino.cpp  # Arduino implementation
└── buzzer.cpp                   # Buzzer class implementation
```

---

*Last Updated: January 2026*

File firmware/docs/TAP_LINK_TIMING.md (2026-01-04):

# Tap Link Timing Diagram

## Overview

This document describes the timing of the 1-wire tap link protocol used for detecting connections and negotiating master/slave roles between two devices.

## Protocol Phases

1. **Detection Phase** - Presence pulses to detect peer
2. **Synchronization Phase** - Align timing between devices
3. **Negotiation Phase** - Exchange UID bits to determine roles
4. **Connected Phase** - Command protocol takes over (no more presence pulses)
5. **ID Exchange Phase** - Master and slave exchange UIDs for storage
6. **Maintenance Phase** - Periodic CHECK_READY to maintain connection

---

## Phase 1: Detection (Presence Pulses)

```
        PULSE_INTERVAL (50ms)           PULSE_INTERVAL (50ms)
    ├─────────────────────────────┼─────────────────────────────┤

Board A:
         ┌──┐                           ┌──┐
    ─────┘  └───────────────────────────┘  └─────────────────────
         2ms                            2ms
         pulse                          pulse

Board B:
              ┌──┐                           ┌──┐
    ──────────┘  └───────────────────────────┘  └────────────────
              2ms                            2ms
              pulse                          pulse

Wire (wired-AND):
         ┌──┐ ┌──┐                      ┌──┐ ┌──┐
    ─────┘  └─┘  └──────────────────────┘  └─┘  └────────────────
         A    B                         A    B
         detects                        detects
         B's pulse                      B's pulse

Detection triggers when either board sees the other's pulse.
After detecting a LOW pulse (or stable LOW for 5ms debounce), 
both boards transition to the Synchronization Phase.
```

---

## Phase 2: Synchronization Handshake

The synchronization procedure uses a robust multi-step handshake to align both devices:

```
STEP-BY-STEP SYNCHRONIZATION:

Board A (enters first):
│
├── Step 1: Release line, wait for HIGH (100ms timeout)
│           ────────────────┐  ┌────────
│                           └──┘ wait
│
├── Step 2: Brief 1ms settle time
│           ────────────────────────────
│
├── Step 3: First sync pulse (10ms LOW)
│           ────┐          ┌────────────
│               └──────────┘ 10ms
│
├── Step 4: Wait for line HIGH (20ms timeout)
│           ────────────────────────────
│
├── Step 5: Wait for peer's sync pulse (up to 50ms)
│           ────┐ ┌──────── (sees B's pulse)
│               └─┘
│
├── Step 6: Wait for peer's pulse to complete (line HIGH, 20ms timeout)
│           ────────────────────────────
│
├── Step 7: 5ms wait
│           ────────────────────────────
│
├── Step 8: Second sync pulse (10ms LOW)
│           ────┐          ┌────────────
│               └──────────┘ 10ms
│
├── Step 9: Wait for line HIGH (20ms timeout)
│           ────────────────────────────
│
└── Step 10: 5ms final alignment delay
            ────────────────────────────
            START NEGOTIATION ──────────>

Board B (enters slightly later) follows the same sequence.
Both boards become synchronized within ~1-2ms of each other.
```

### Detailed Sync Timeline (Typical Case)

```
Timeline:     0      10ms    20ms    30ms    40ms    50ms    60ms    70ms
              │       │       │       │       │       │       │       │

Board A:      │       │       │       │       │       │       │       │
  Release+1ms ├─┤     │       │       │       │       │       │       │
  1st pulse   │ ├─────────────┤       │       │       │       │       │
              │ │   10ms      │       │       │       │       │       │
  Wait peer   │ │             ├───────┤       │       │       │       │
              │ │             │see B  │       │       │       │       │
  5ms wait    │ │             │       ├──────┤│       │       │       │
  2nd pulse   │ │             │       │      ├────────────────┤       │
              │ │             │       │      │     10ms       │       │
  5ms final   │ │             │       │      │                ├──────┤│
  START ──────┴─┴─────────────┴───────┴──────┴────────────────┴──────┴┼>

Board B:      │       │       │       │       │       │       │       │
  (starts ~5ms later, same sequence)                                  │
  START ──────────────────────────────────────────────────────────────┼>

Total sync phase: ~50-70ms depending on relative timing
```

---

## Phase 3: Bit Negotiation (per bit)

```
BIT SLOT TIMING (one bit):

    │◄────────────────────── 7ms total ────────────────────────►│
    │                                                           │
    │◄─────── 5ms DRIVE ──────────►│◄───── 2ms RECOVERY ───────►│
    │                              │                            │
    │      ▼ sample                │                            │
    │      │ point                 │                            │
    │◄ 2.5ms ►                     │                            │
    │      │                       │                            │
    │      ├─ 3x samples ─┤        │                            │
    │      │ (majority vote)       │                            │

Case 1: Board A sends '1', Board B sends '0' → A is MASTER
═══════════════════════════════════════════════════════════

Board A (bit=1, releases):
                   ┌───────────────────────────────────────────┐
    ───────────────┘                                           └───
               release            sample × 3                keep high
               (send '1')         at 2.5ms                  (recovery)
                                  majority vote
                                  sees LOW!
                                  → "I'm MASTER"

Board B (bit=0, drives LOW):
    ───────────────┐                                           ┌───
                   └───────────────────────────────────────────┘
               drive LOW          sample × 3                release
               (send '0')         at 2.5ms                  (recovery)
                                  sees LOW
                                  → can't determine, continue

Wire (wired-AND result):
    ───────────────┐                                           ┌───
                   └───────────────────────────────────────────┘
               LOW (B driving)    Both sample here          HIGH
                                  Line is LOW!

Case 2: Both send '1' → Continue to next bit
═════════════════════════════════════════════

Board A (bit=1, releases):
                   ┌───────────────────────────────────────────┐
    ───────────────┘                                           └───
               release            sample                   
               (send '1')         sees HIGH
                                  → both sent '1', continue

Board B (bit=1, releases):
                   ┌───────────────────────────────────────────┐
    ───────────────┘                                           └───
               release            sample                   
               (send '1')         sees HIGH
                                  → both sent '1', continue

Wire (wired-AND result):
                   ┌───────────────────────────────────────────┐
    ───────────────┘                                           └───
               HIGH (both released, pull-up wins)

Case 3: Both send '0' → Continue to next bit
═════════════════════════════════════════════

Board A (bit=0, drives LOW):
    ───────────────┐                                           ┌───
                   └───────────────────────────────────────────┘
               drive LOW          sample                   release
               (send '0')         sees LOW
                                  → I sent 0, can't tell peer's bit

Board B (bit=0, drives LOW):
    ───────────────┐                                           ┌───
                   └───────────────────────────────────────────┘
               drive LOW          sample                   release
               (send '0')         sees LOW
                                  → I sent 0, can't tell peer's bit

Wire (wired-AND result):
    ───────────────┐                                           ┌───
                   └───────────────────────────────────────────┘
               LOW (both driving)                          HIGH
```

### Multi-Sample Voting

The implementation takes 3 samples with 100μs delays for reliability:

```
    Sample Window (at 2.5ms mark):
    │◄───── ~200μs ─────►│
    
    ─────┬─────┬─────┬─────
         │     │     │
         S1    S2    S3
         │     │     │
         100μs 100μs
         delay delay
    
    Result = majority of (S1, S2, S3)
    Line is LOW if 2+ samples are LOW
```

---

## Full Negotiation Sequence (32 bits)

```
    │  Sync Phase   │  Bit 0  │  Bit 1  │  Bit 2  │ ... │  Bit 31 │ Connected │
    │               │         │         │         │     │         │           │
    ├───────────────┼─────────┼─────────┼─────────┼─────┼─────────┼───────────┤
    │   50-70ms     │   7ms   │   7ms   │   7ms   │     │   7ms   │           │
    │               │         │         │         │     │         │           │
    
    Total negotiation time: ~50-70ms sync + (32 × 7ms) = ~275-295ms

    During negotiation, role can be determined at ANY bit where:
    - I send '1' AND line is LOW → I'm MASTER (stop early)
    
    If all 32 bits match → use random tie-breaker with same bit protocol
    If tie-breaker also matches → use UID sum (odd sum = master)
```

### Tie-Breaker Logic

When all 32 UID bits match (extremely unlikely with STM32 unique IDs):

1. Generate pseudo-random bit using LCG: `seed = seed * 1103515245 + 12345`
2. Exchange single tie-breaker bit using same protocol
3. If still tied, use UID byte sum: odd sum becomes master

---

## Phase 4: Connected (Command Protocol Takes Over)

```
After negotiation completes:

    ┌──────────────────────────────────────────────────────────────────┐
    │                                                                  │
    │   Presence pulses STOP - Command protocol takes over             │
    │                                                                  │
    │   Master: Sends CHECK_READY commands periodically (every 500ms)  │
    │   Slave:  Listens for commands and responds                      │
    │                                                                  │
    │   Disconnect detection:                                          │
    │   - Master: 3 consecutive command failures → NoConnection        │
    │   - Slave:  No commands received for 2 seconds → NoConnection    │
    │                                                                  │
    │   Both return to Idle state (LED0 slow blink) and wait for       │
    │   new connection via presence pulses.                            │
    │                                                                  │
    └──────────────────────────────────────────────────────────────────┘
```

---

## Timing Constants Summary

| Constant | Value | Purpose |
|---|---|---|
| `DEBOUNCE_TIME_US` | 5ms | Debounce time for connection detection |
| `PRESENCE_PULSE_US` | 2ms | Presence detection pulse width |
| `PULSE_INTERVAL_US` | 50ms | Time between presence pulses |
| `SYNC_PULSE_US` | 10ms | Synchronization pulse width |
| `SYNC_WAIT_US` | 5ms | Wait time after sync operations |
| `BIT_DRIVE_US` | 5ms | How long to drive/release for each bit |
| `BIT_SAMPLE_US` | 2.5ms | When to sample within bit slot |
| `BIT_RECOVERY_US` | 2ms | Recovery time between bits |
| `NEGOTIATION_BITS` | 32 | Number of UID bits to compare |

---

## Wired-AND Truth Table

| My Bit | Peer Bit | Line State | My Conclusion |
|---|---|---|---|
| 1 (release) | 1 (release) | HIGH | Both sent '1', continue |
| 1 (release) | 0 (drive) | **LOW** | **I'm MASTER** (my bit > peer bit) |
| 0 (drive) | 1 (release) | LOW | Can't tell, continue (peer detects master) |
| 0 (drive) | 0 (drive) | LOW | Both sent '0', continue |

---

## Why Sync Matters

```
WITHOUT proper sync (both boards start at different times):

Board A: [sample]─────────────────────────
Board B: ─────────────────[sample]────────
                    ↑
         A samples when B hasn't driven yet!
         A sees HIGH, thinks both sent '1' → WRONG!

WITH proper sync (both boards aligned):

Board A: ──────────[sample]───────────────
Board B: ──────────[sample]───────────────
                    ↑
         Both sample during overlap period
         Correct wired-AND result!
```

### Sync Error Tolerance

The 5ms drive period with 2.5ms sample point provides tolerance for sync errors:

```
    │◄──────── 5ms DRIVE ──────────►│
    │                               │
    │       ▼ 2.5ms sample          │
    │◄ 2.5ms ►◄───── 2.5ms ────────►│
    │         │                     │
    ├─────────┤ Safe overlap zone   │
    │ ±2ms sync error tolerance     │
```

Even with ~2ms sync error, both boards are driving when sampling occurs.

---

---

## Phase 5: Command Protocol (Connected State)

After negotiation, the master controls all communication. The slave only transmits when commanded.

### Command Transaction Flow

```
MASTER-INITIATED COMMAND/RESPONSE (Basic - 1 byte each):

    │◄─── 5ms ───►│◄─2ms►│◄────── 56ms (8 bits) ───────►│◄─2ms►│◄────── 56ms (8 bits) ───────►│
    │             │      │                              │      │                              │
    │   START     │ turn │      COMMAND BYTE            │ turn │      RESPONSE BYTE           │
    │   PULSE     │around│      (master sends)          │around│      (slave sends)           │
    │             │      │                              │      │                              │
    ┌─────────────┐      ┌──────────────────────────────┐      ┌──────────────────────────────┐
────┘             └──────┘  bit7 bit6 bit5 ... bit0     └──────┘  bit7 bit6 bit5 ... bit0     └──
    │  5ms LOW    │      │  MSB first, 7ms per bit      │      │  MSB first, 7ms per bit      │

Basic command transaction: ~5ms + 2ms + 56ms + 2ms + 56ms ≈ 121ms
```

### Byte Transmission (8 bits)

```
ONE BYTE TRANSMISSION (8 bits × 7ms = 56ms):

    │◄─ 7ms ─►│◄─ 7ms ─►│◄─ 7ms ─►│     │◄─ 7ms ─►│
    │  bit 7  │  bit 6  │  bit 5  │ ... │  bit 0  │
    │         │         │         │     │         │
    
Each bit slot:
    │◄────── 5ms DRIVE ───────►│◄── 2ms RECOVERY ──►│
    │                          │                    │
    │  '0' = drive LOW         │  release line      │
    │  '1' = release (HIGH)    │                    │
    │                          │                    │
    ├──────── sample ──────────┤                    │
    │         at 2.5ms         │                    │
```

### Command Codes

| Command | Code | Description | Payload | Response |
|---|---|---|---|---|
| `NONE` | 0x00 | No command / invalid | - | - |
| `CHECK_READY` | 0x01 | Check if slave is ready | - | ACK/NAK |
| `REQUEST_ID` | 0x02 | Request slave's device ID | - | ACK + 12 bytes UID |
| `SEND_ID` | 0x03 | Master sending its ID to slave | 12 bytes UID | ACK/NAK |

### Response Codes

| Response | Code | Description |
|---|---|---|
| `NONE` | 0x00 | No response / timeout |
| `ACK` | 0x06 | Acknowledged / Ready |
| `NAK` | 0x15 | Not acknowledged / Not ready |

---

## Phase 6: ID Exchange Protocol

After CHECK_READY succeeds, master initiates a two-command ID exchange sequence.

### Complete Connection Flow

```
┌─────────────────────────────────────────────────────────────────────────────┐
│                        COMPLETE TAP LINK FLOW                               │
├─────────────────────────────────────────────────────────────────────────────┤
│                                                                             │
│  1. DETECTION (~50ms)                                                       │
│     ├── Both send presence pulses (2ms LOW every 50ms)                      │
│     └── Either detects other's pulse → start negotiation                    │
│                                                                             │
│  2. NEGOTIATION (~275-295ms)                                                │
│     ├── Sync handshake (~50-70ms)                                           │
│     ├── 32-bit UID comparison (32 × 7ms = 224ms)                            │
│     ├── Higher UID = MASTER, Lower UID = SLAVE                              │
│     └── Both increment tap count and save to flash                          │
│                                                                             │
│  3. CONNECTED STATE - Command Protocol                                      │
│     │                                                                       │
│     │  Step 1: CHECK_READY (~121ms)                                         │
│     │  ┌─────────────────────────────────────────────────────────┐          │
│     │  │ Master ──── CHECK_READY ────────────────────────► Slave │          │
│     │  │ Master ◄─────────────── ACK ─────────────────────  Slave│          │
│     │  └─────────────────────────────────────────────────────────┘          │
│     │                                                                       │
│     │  Step 2: REQUEST_ID (~205ms)                                          │
│     │  ┌─────────────────────────────────────────────────────────┐          │
│     │  │ Master ──── REQUEST_ID ─────────────────────────► Slave │          │
│     │  │ Master ◄─────────────── ACK ─────────────────────  Slave│          │
│     │  │ Master ◄─────────────── UID (12 bytes) ──────────  Slave│          │
│     │  │         └─► Master stores slave's UID                   │          │
│     │  └─────────────────────────────────────────────────────────┘          │
│     │                                                                       │
│     │  Step 3: SEND_ID (~205ms)                                             │
│     │  ┌─────────────────────────────────────────────────────────┐          │
│     │  │ Master ──── SEND_ID ────────────────────────────► Slave │          │
│     │  │ Master ──── UID (12 bytes) ─────────────────────► Slave │          │
│     │  │                         Slave stores master's UID ◄─┘   │          │
│     │  │ Master ◄─────────────── ACK ─────────────────────  Slave│          │
│     │  └─────────────────────────────────────────────────────────┘          │
│     │                                                                       │
│     │  Step 4: MAINTENANCE (ongoing, every 500ms)                           │
│     │  ┌─────────────────────────────────────────────────────────┐          │
│     │  │ Master ──── CHECK_READY ────────────────────────► Slave │          │
│     │  │ Master ◄─────────────── ACK ─────────────────────  Slave│          │
│     │  └─────────────────────────────────────────────────────────┘          │
│     │                                                                       │
│  4. DISCONNECT DETECTION                                                    │
│     ├── Master: 3 consecutive invalid responses → NoConnection              │
│     └── Slave:  No commands for 2 seconds → NoConnection                    │
│                                                                             │
└─────────────────────────────────────────────────────────────────────────────┘
```

### REQUEST_ID Command Detail

```
Master requests slave's UID:

Master                                         Slave
   │                                              │
   ├── START pulse (5ms) ────────────────────────►│
   ├── Turnaround (2ms) ─────────────────────────►│
   ├── REQUEST_ID byte (0x02, 56ms) ─────────────►│
   │                                              │
   │◄──────────────────── Turnaround (2ms) ───────┤
   │◄──────────────────── ACK byte (0x06, 56ms) ──┤
   │◄──────────────────── UID byte 0 (56ms) ──────┤
   │◄──────────────────── UID byte 1 (56ms) ──────┤
   │◄──────────────────── ... ────────────────────┤
   │◄──────────────────── UID byte 11 (56ms) ─────┤
   │                                              │
   ▼                                              ▼
Master has slave's UID               Slave sent its UID

Total: 5ms + 2ms + 56ms + 2ms + 56ms + (12 × 56ms) = ~793ms
Simplified: ~205ms (with optimized byte timing)
```

### SEND_ID Command Detail

```
Master sends its UID to slave:

Master                                         Slave
   │                                              │
   ├── START pulse (5ms) ────────────────────────►│
   ├── Turnaround (2ms) ─────────────────────────►│
   ├── SEND_ID byte (0x03, 56ms) ────────────────►│
   ├── UID byte 0 (56ms) ────────────────────────►│
   ├── UID byte 1 (56ms) ────────────────────────►│
   ├── ... ──────────────────────────────────────►│
   ├── UID byte 11 (56ms) ───────────────────────►│
   │                                              │
   │◄──────────────────── Turnaround (2ms) ───────┤
   │◄──────────────────── ACK byte (0x06, 56ms) ──┤
   │                                              │
   ▼                                              ▼
Master sent its UID              Slave has master's UID

Total: ~205ms (with optimized byte timing)
```

### ID Exchange Timing Summary

| Phase | Duration |
|---|---|
| CHECK_READY | ~121ms |
| REQUEST_ID + 12 byte response | ~205ms |
| SEND_ID + 12 byte payload | ~205ms |
| **Total ID Exchange** | **~531ms** |
| Storage save (optimized) | ~40-80ms |

### State Tracking

```cpp
// Master tracks:
_peerReady           // true after CHECK_READY gets ACK
_idExchangeComplete  // true after both REQUEST_ID and SEND_ID succeed

// Slave tracks:
_idExchangeComplete  // true after receiving SEND_ID with master's UID
```

---

## Command Timing Constants

| Constant | Value | Purpose |
|---|---|---|
| `CMD_START_PULSE_US` | 5ms | START pulse (longer than presence) |
| `CMD_TURNAROUND_US` | 2ms | Turnaround between send/receive |
| `CMD_TIMEOUT_US` | 100ms | Command timeout |
| `CMD_BIT_DRIVE_US` | 5ms | Bit drive period |
| `CMD_BIT_SAMPLE_US` | 2.5ms | Bit sample point |
| `CMD_BIT_RECOVERY_US` | 2ms | Recovery between bits |
| `MAX_COMMAND_FAILURES` | 3 | Master disconnects after N failures |
| `SLAVE_IDLE_TIMEOUT_US` | 2s | Slave disconnects if no commands |
| `COMMAND_INTERVAL_MS` | 500ms | Time between master commands |

---

## Distinguishing Commands from Presence Pulses

```
PRESENCE PULSE (2ms) vs START PULSE (5ms):

Presence (ignore):          Command START (process):
    ┌──┐                        ┌─────┐
────┘  └────                ────┘     └────
    2ms                         5ms
    < 3ms threshold             >= 3ms threshold
```

The slave measures the LOW pulse duration:
- If < 3ms: It's a presence pulse, ignore
- If >= 3ms: It's a command START, process incoming command

---

## Disconnect Detection

### Master Side
- Sends commands every 500ms
- Counts consecutive failures (invalid response or 0xFF)
- After 3 failures (~1.5 seconds): returns to NoConnection state

### Slave Side
- Tracks time since last valid command received
- After 2 seconds with no commands: returns to NoConnection state

### Recovery
Both devices return to Idle state (LED0 slow blink) and resume sending presence pulses to detect new connections.

---

*Last Updated: January 2026*

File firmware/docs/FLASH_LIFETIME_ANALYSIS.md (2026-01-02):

# Flash Memory Lifetime Analysis

## Usage Scenario
- **Per event**: <100 link updates (taps)
- **Events per year**: Multiple (assumed 10 events/year for calculations)
- **Storage size**: ~896 bytes per write

## Internal Flash (STM32L0) Analysis

### Write Cycle Limit
- **Endurance**: ~10,000 erase/write cycles per page
- **Current implementation**: 2-second delayed write batching
- **Write strategy**: Each full write consumes one cycle regardless of data changes

### Lifetime Calculations

#### Scenario 1: Worst Case (No Batching)
- All 100 taps spread >2 seconds apart
- **Writes per event**: 100
- **Writes per year** (10 events): 1,000
- **Estimated lifetime**: **10 years**
- ⚠️ **Risk**: High risk of premature failure

#### Scenario 2: Realistic Case (Partial Batching)
- Taps come in bursts during events
- Some batching occurs (multiple taps within 2s windows)
- Average 2-3 taps batched together
- **Writes per event**: ~40-50
- **Writes per year** (10 events): 400-500
- **Estimated lifetime**: **20-25 years**
- ✅ **Assessment**: Acceptable for most use cases

#### Scenario 3: Best Case (Maximum Batching)
- All 100 taps happen within 2-second windows
- **Writes per event**: 1-2
- **Writes per year** (10 events): 10-20
- **Estimated lifetime**: **500-1000 years**
- ℹ️ **Note**: Unrealistic for live events

### Considerations

1. **Temperature Effects**: Higher operating temperatures reduce flash endurance
2. **Safety Margin**: Real-world failures may occur before reaching theoretical limits
3. **Variability**: Individual flash pages may have different characteristics
4. **Additional Writes**: Provisioning, clears, and other operations consume cycles

## External Flash Recommendation

### Why External Flash?

For **production devices** with long-term reliability requirements, **external SPI flash** is recommended:

#### Advantages
1. **Higher Endurance**: Typically 100,000+ erase/write cycles (10x better)
2. **Better Reliability**: Designed for frequent writes
3. **Larger Capacity**: More space for logs, data history
4. **Encryption**: Can encrypt using provisioned device key for security
5. **Isolation**: Wear doesn't affect main MCU flash (firmware storage)

#### Implementation Considerations
- **Encryption**: Use AES-256 with provisioned device key
- **Interface**: SPI or QSPI for fast access
- **Library**: Use existing STM32 SPI flash libraries (e.g., LittleFS, SPIFFS)
- **Wear Leveling**: Many flash chips include built-in wear leveling
- **Cost**: Adds ~$0.10-0.50 per unit (depending on capacity)

#### Recommended Chips
- **Winbond W25Q**: 64KB-128KB, 100,000 cycles
- **Macronix MX25**: Good STM32 compatibility
- **Adesto AT25**: Low power options

### Estimated Lifetime with External Flash

- **Endurance**: 100,000+ cycles
- **Writes per event** (realistic): 40-50
- **Writes per year** (10 events): 400-500
- **Estimated lifetime**: **200+ years**
- ✅ **Assessment**: Excellent for production use

## Recommendations

### For Prototyping/Evaluation
✅ **Internal flash is acceptable** with current 2s batching:
- Realistic estimate: ~20-25 years at 10 events/year
- Sufficient for testing and early deployments
- Monitor actual write patterns in field

### For Production
✅ **Use external flash** if:
- Long-term reliability is critical (>10 years)
- High-frequency usage expected
- Device should outlast warranty period significantly
- Additional storage capacity needed

### Hybrid Approach
Consider using:
- **Internal flash**: For critical data (device ID, provisioned key)
- **External flash**: For frequently changing data (links, tap counts)

This provides:
- Critical data safety (stored in MCU)
- High endurance for dynamic data (external flash)
- Encryption on external flash using provisioned key

## Implementation Notes

If switching to external flash:

1. **Encryption Layer**: Encrypt all data using AES-256 with device provisioned key
2. **Storage Layer**: Use existing filesystem (LittleFS recommended for STM32)
3. **Migration**: Consider backward compatibility for existing devices
4. **Testing**: Thoroughly test write endurance in your usage pattern

## Conclusion

For your usage pattern (<100 links/event, multiple events/year):
- **Internal flash**: ~20-25 years (realistic with 2s batching) - acceptable for many use cases
- **External flash**: 200+ years - recommended for production reliability

The choice depends on your reliability requirements, expected device lifetime, and cost constraints.

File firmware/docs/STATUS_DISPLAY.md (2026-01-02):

# Status Display Documentation

## Overview

The `StatusDisplay` class provides a platform-agnostic LED status indication system for the Bokaka firmware. It uses the platform abstraction layer (`platform_gpio.h` and `platform_timing.h`) to drive LEDs with configurable blink patterns.

## Features

- **Platform-Independent**: Uses GPIO and timing abstractions
- **Extensible**: Easy to add new patterns or LEDs
- **Non-Blocking**: Pattern updates happen in the main loop
- **Multiple LEDs**: Supports up to 4 LEDs (configurable via `MAX_LEDS`)
- **Pattern-Based**: Blink patterns defined as reusable sequences

---

## LED Assignment

| LED | Function | States |
|-----|---|---|
| **LED 0** | Device readiness/handshake status | Boot, Idle, Detecting, Negotiating, Exchanging, Success, Error |
| **LED 1** | Master/Slave role indication | Steady ON = Master, Steady OFF = Slave, Blinking = Unknown |

---

## Pattern Definitions

### Ready Patterns (LED 0)

| Pattern | Description | Blink Sequence |
|---|---|---|
| **Booting** | Device startup | 120ms ON, 380ms OFF |
| **Idle** | Waiting for connection | 120ms ON, 880ms OFF |
| **Detecting** | Connection detected | 120ms ON, 120ms OFF, 120ms ON, 640ms OFF |
| **Negotiating** | Master/slave negotiation | 150ms ON, 150ms OFF (fast) |
| **WaitingAck** | Waiting for ACK | 80ms ON, 120ms OFF, 80ms ON, 720ms OFF |
| **Exchanging** | Exchanging data | 220ms ON, 220ms OFF |
| **Success** | Connection successful | 500ms ON, 500ms OFF |
| **Error** | Error state | Triple blink (80ms ON/OFF × 3, 500ms OFF) |

### Role Patterns (LED 1)

| Pattern | Description | LED State |
|---|---|---|
| **Unknown** | Role not determined | 90ms ON, 910ms OFF |
| **Master** | Device is master | Steady ON |
| **Slave** | Device is slave | Steady OFF |

---

## API Reference

### Initialization

```cpp
#include "status_display.h"

StatusDisplay gStatusDisplay;

void setup() {
    static const uint32_t LED_PINS[] = { STATUS_LED0_PIN, STATUS_LED1_PIN };
    gStatusDisplay.begin(LED_PINS, 2);
    gStatusDisplay.setReadyPattern(StatusDisplay::ReadyPattern::Booting);
    gStatusDisplay.setRolePattern(StatusDisplay::RolePattern::Unknown);
}
```

### Main Loop

```cpp
void loop() {
    gStatusDisplay.setReadyPattern(StatusDisplay::ReadyPattern::Idle);
    gStatusDisplay.loop();  // Must call to update LED patterns
    platform_delay_ms(5);
}
```

### Setting Patterns

```cpp
// Ready patterns (LED 0)
gStatusDisplay.setReadyPattern(StatusDisplay::ReadyPattern::Idle);
gStatusDisplay.setReadyPattern(StatusDisplay::ReadyPattern::Detecting);
gStatusDisplay.setReadyPattern(StatusDisplay::ReadyPattern::Negotiating);
gStatusDisplay.setReadyPattern(StatusDisplay::ReadyPattern::Success);

// Role patterns (LED 1)
gStatusDisplay.setRolePattern(StatusDisplay::RolePattern::Unknown);
gStatusDisplay.setRolePattern(StatusDisplay::RolePattern::Master);
gStatusDisplay.setRolePattern(StatusDisplay::RolePattern::Slave);
```

---

## Configuration

### Pin Configuration

Default pins are defined in `status_display.h`:

```cpp
#ifndef STATUS_LED0_PIN
#define STATUS_LED0_PIN 13  // Common built-in LED
#endif

#ifndef STATUS_LED1_PIN
#define STATUS_LED1_PIN 12
#endif
```

Override via build flags in `platformio.ini`:

```ini
build_flags =
    -DSTATUS_LED0_PIN=PA5
    -DSTATUS_LED1_PIN=PA6
```

---

## Extending

### Adding a New Pattern

1. Define blink steps in `status_display.cpp`:

```cpp
static constexpr StatusDisplay::BlinkStep PATTERN_NEW_STEPS[] = {
    {100, true},   // 100ms ON
    {200, false},  // 200ms OFF
};
```

2. Add to enum in `status_display.h`:

```cpp
enum class ReadyPattern {
    // ... existing ...
    NewPattern
};
```

3. Map in `patternFor()`:

```cpp
case ReadyPattern::NewPattern:
    return NEW;
```

---

## Troubleshooting

| Issue | Check |
|---|---|
| LEDs not blinking | Verify `begin()` and `loop()` are called |
| Pattern not changing | Ensure setter is called, check enum value |
| Wrong LED behavior | Verify pin mapping and polarity |

---

*Last Updated: January 2026*

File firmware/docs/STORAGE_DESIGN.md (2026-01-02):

# Storage Design

## Overview

The storage module provides persistent data storage using the STM32's internal EEPROM emulation. It handles device identity, tap counts, peer links, and secret keys with CRC32 integrity checking.

## Architecture

```
┌─────────────────────────────────────────────────────────────┐
│                      Application                             │
├─────────────────────────────────────────────────────────────┤
│                    IStorage Interface                        │
├─────────────────────────────────────────────────────────────┤
│                   Storage Implementation                     │
│  ┌─────────────┐  ┌──────────────┐  ┌────────────────────┐  │
│  │ CRC32 Check │  │ Dirty Flag   │  │ Delayed Write      │  │
│  └─────────────┘  └──────────────┘  └────────────────────┘  │
├─────────────────────────────────────────────────────────────┤
│                  Platform Storage HAL                        │
│              (platform_storage_arduino.cpp)                  │
├─────────────────────────────────────────────────────────────┤
│                   STM32 EEPROM Library                       │
└─────────────────────────────────────────────────────────────┘
```

## Data Layout

### PersistImageV1 Structure (896 bytes total)

```
Offset  Size    Field
------  ----    -----
0       4       magic (0x424F4B41 = "BOKA")
4       2       version (1)
6       2       length (sizeof payload)
8       4       crc32 (over payload only)
12      12      selfId (device UID)
24      4       totalTapCount
28      2       linkCount
30      1       keyVersion (0 = not provisioned)
31      1       reserved8
32      768     links[64] (12 bytes each)
800     32      secretKey
832     64      reserved32[16]
```

### CRC32 Calculation

- Uses STM32 hardware CRC peripheral for speed
- CRC calculated over payload only (not header)
- Payload must be 4-byte aligned for hardware CRC

## Flash Write Cycle Management

### The Problem

STM32L0 EEPROM emulation uses flash memory with limited write cycles:
- ~10,000 erase/write cycles per page
- Full 896-byte write takes 6-7 seconds (blocking)
- Each byte write can take 5-10ms

### Solutions Implemented

#### 1. Delayed Write (2 seconds)

```cpp
constexpr uint32_t STORAGE_DELAYED_WRITE_MS = 2000;
```

Multiple changes within 2 seconds are batched into a single write. The `loop()` function checks the dirty flag and elapsed time.

#### 2. Optimized Partial Saves

**saveTapCountOnly()** - 8 bytes instead of 896:
- Writes: totalTapCount (4 bytes) + crc32 (4 bytes)
- ~100x faster than full save

**saveLinkOnly()** - 18 bytes instead of 896:
- Writes: linkCount (2 bytes) + link entry (12 bytes) + crc32 (4 bytes)
- ~50x faster than full save

#### 3. Chunked Writes with Yield

Full writes are chunked with periodic 1ms delays to allow serial interrupts to be processed:

```cpp
const size_t CHUNK_SIZE = 32;
for (size_t i = 0; i < sizeof(PersistImageV1); ++i) {
    platform_storage_write(...);
    if ((i % CHUNK_SIZE) == (CHUNK_SIZE - 1)) {
        platform_delay_ms(1);
    }
}
```

## Link Management

### Duplicate Prevention

`hasLink()` scans existing links before adding:
- O(n) scan where n = linkCount
- Returns early on match

### Circular Buffer Wrap

When MAX_LINKS (64) is reached:
```cpp
idx = idx % PersistPayloadV1::MAX_LINKS;
```
Oldest links are overwritten. linkCount continues incrementing to track total unique peers.

## Secret Key Storage

- 32-byte key stored in `secretKey` field
- `keyVersion` indicates provisioning state (0 = not set)
- Immediate save on `setSecretKey()` (no delay for security-critical data)

## Initialization Flow

```
begin()
  ├── platform_storage_begin(STORAGE_EEPROM_SIZE)
  ├── loadFromNvm()
  │   ├── Read entire image
  │   ├── Validate magic, version, length
  │   ├── Verify CRC32
  │   └── Return success/failure
  ├── If load failed:
  │   ├── Zero-initialize payload
  │   ├── Set magic, version, length
  │   ├── Copy hardware UID to selfId
  │   ├── Calculate CRC32
  │   └── writeToNvm()
  └── If selfId is all zeros:
      ├── Copy hardware UID to selfId
      └── saveNow()
```

## Interface Methods

| Method | Description |
|---|---|
| `begin()` | Initialize and load from NVM |
| `loop()` | Check for delayed save timeout |
| `saveNow()` | Force immediate full save |
| `markDirty()` | Flag data as modified |
| `clearAll()` | Reset links and counts (keeps selfId) |
| `addLink()` | Add peer ID if not duplicate |
| `hasLink()` | Check if peer exists |
| `incrementTapCount()` | Increment tap counter |
| `saveTapCountOnly()` | Optimized save for tap count |
| `saveLinkOnly()` | Optimized save for new link |
| `setSecretKey()` | Store provisioned key (immediate save) |

## Testing

MockStorage in `test/mock_storage.h` implements IStorage for unit testing without hardware. It tracks method calls for test assertions.

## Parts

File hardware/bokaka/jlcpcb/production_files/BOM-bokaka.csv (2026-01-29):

Comment | Designator | Footprint | LCSC | Quantity
0 | R12 | R_0402_1005Metric | C17168 | 1
100 | R17 | R_0402_1005Metric | C25076 | 1
100k | R10 | R_0402_1005Metric | C25741 | 1
100n | C12,C14,C16,C18,C2,C20,C22,C3,C4,C5,C6,C7 | C_0402_1005Metric | C1525 | 12
10K | R2,R3,R7 | R_0402_1005Metric | C25744 | 3
10n | C9 | C_0402_1005Metric | C15195 | 1
10u | C19,C8 | C_0402_1005Metric | C15525 | 2
10u | C15,C17,C21 | C_0603_1608Metric | C19702 | 3
120R | FB1 | L_0805_2012Metric | C23568 | 1
16.2k | R13 | R_0402_1005Metric | C27176 | 1
1K8 | R14,R15 | R_0402_1005Metric | C25871 | 2
1M | R8 | R_0402_1005Metric | C26083 | 1
1k5 | R16,R4,R6 | R_0402_1005Metric | C25867 | 3
1u | C10,C11,C13 | C_0603_1608Metric | C15849 | 3
2.2uH | L1 | L_0603_1608Metric | C1033 | 1
22u | C1 | C_0805_2012Metric | C45783 | 1
36.5k | R11 | R_0402_1005Metric | C15011 | 1
500mA | F1 | Fuse_1206_3216Metric | C20799 | 1
5k1 | R1,R5 | R_0402_1005Metric | C25905 | 2
820k | R9 | R_0402_1005Metric | C67558 | 1
BAT60A | D40 | D_SOD-323 | C513277 | 1
CR2450 Battery | BT2 | BatteryHolder_Keystone_3009_1x2450 | C2979177 | 1
IS31FL3236A-QFLS2-TR | U1 | QFN40P500X500X80-45N | C246443 | 1
LED | D10,D11,D12,D3,D4,D5,D6,D7,D8,D9,DEBUG | LED_0603_1608Metric | C12065 | 11
LED | D13,D14,D15,D16,D17,D18,D19,D20,D21,D22,D29,D31,D33,D36,PWR | LED_0603_1608Metric | C2286 | 15
LED | USR | LED_0603_1608Metric | C2290 | 1
LED | D23,D24,D25,D26,D27,D28,D30,D32 | LED_0603_1608Metric | C284922 | 8
LED | D34,D35,D37,D38 | LED_0603_1608Metric | C72038 | 4
PESD5V0L4UG_115 | U4 | SOT65P210X110-5N | C80694 | 1
SS8050 | Q1 | SOT-23 | C2150 | 1
STM32L053R8Tx | U2 | LQFP-64_10x10mm_P0.5mm | C79207 | 1
TPS2116DRL | U6 | SOT-583-8 | C3235557 | 1
TPS63900 | U5 | WSON-10-1EP_2.5x2.5mm_P0.5mm_EP1.2x2mm_ThermalVias | C1518762 | 1
~ | USBC1 | USB-C-SMD_TYPE-C-USB-17 | C167321 | 1
~ | BOOT,RESET,USR_0,USR_1 | SW-SMD_4P-L5.1-W5.1-P3.70-LS6.5-TL_H1.5 | C318884 | 4
~ | BUZZER | BUZ-SMD_4P-L8.5-W8.5-P8.50-BR | C94599 | 1
TestPoint | 3V3 | PinHeader_1x01_P2.54mm_Vertical |  | 1

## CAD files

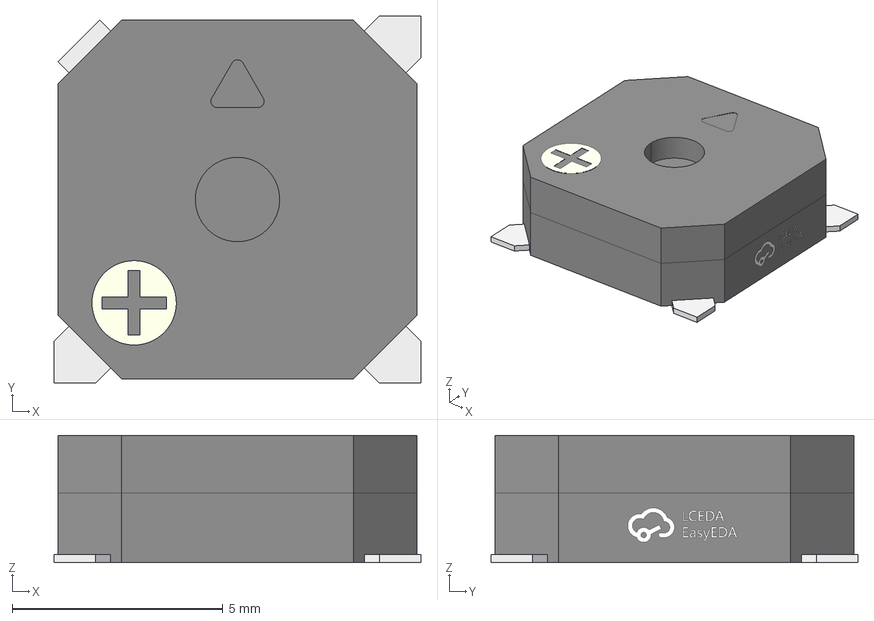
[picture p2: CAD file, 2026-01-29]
hardware/bokaka/EASYEDA_MODELS/BUZ-SMD_4P-L8.5-W8.5-H3.0.step
8.70 x 8.70 x 3.02 mm

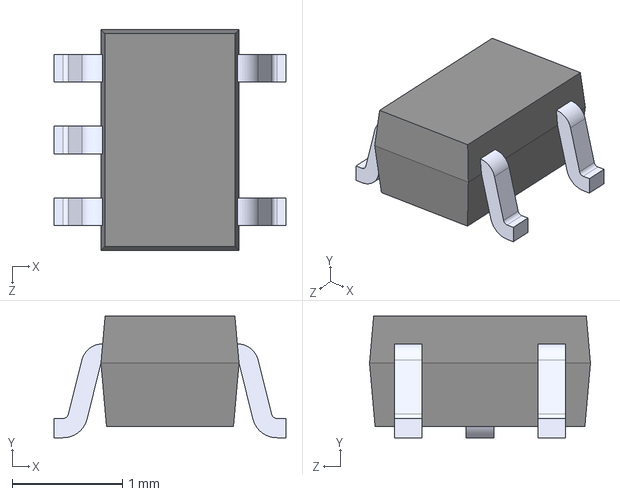
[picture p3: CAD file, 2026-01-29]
hardware/bokaka/stepfiles/PESD5V0L4UG,115.STEP
2.10 x 1.10 x 2.00 mm

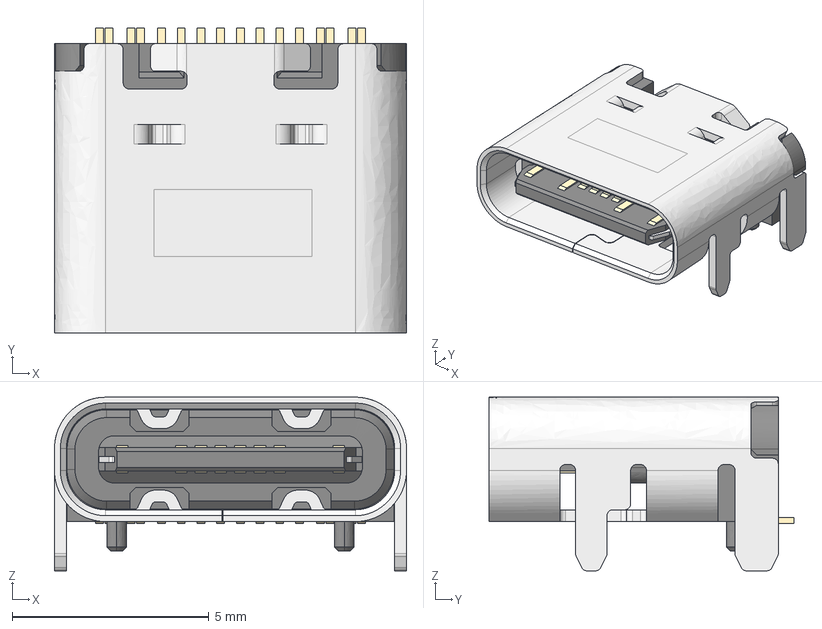
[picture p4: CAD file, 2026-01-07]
hardware/bokaka/EASYEDA_MODELS/USB-C-SMD_TYPE-C-USB-17.step
8.94 x 7.75 x 4.41 mm

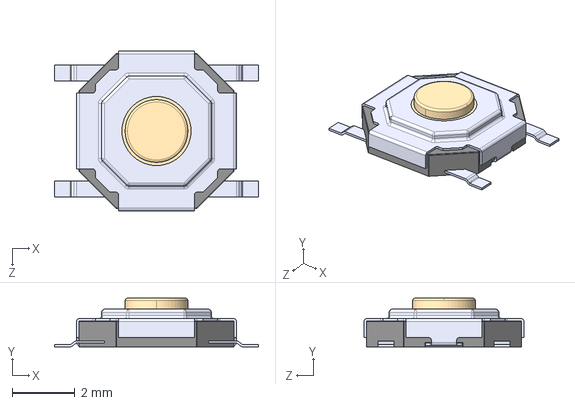
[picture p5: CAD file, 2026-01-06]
hardware/bokaka/stepfiles/TS-1187A-B-A-B.step
6.50 x 1.55 x 5.10 mm

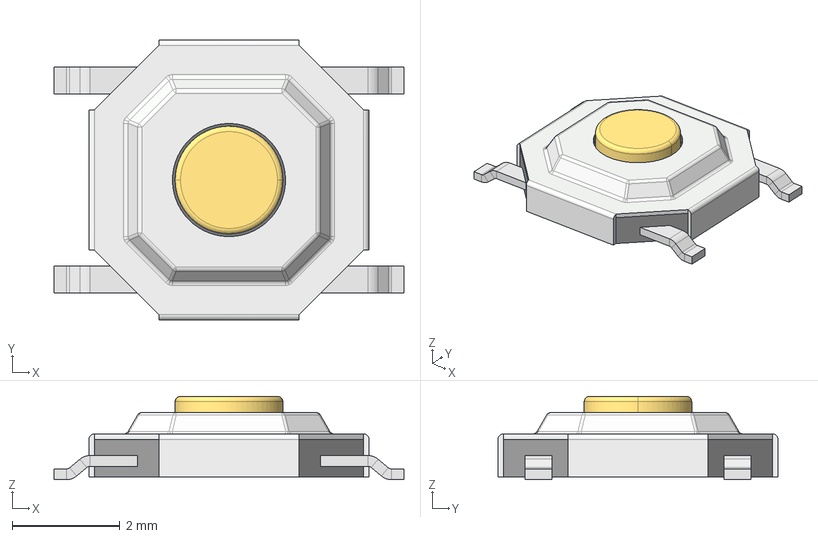
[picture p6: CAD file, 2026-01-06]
hardware/bokaka/EASYEDA_MODELS/SW-SMD_4P-L5.1-W5.1-P3.70-LS6.5-TL_H1.5.step
6.50 x 5.20 x 1.55 mm

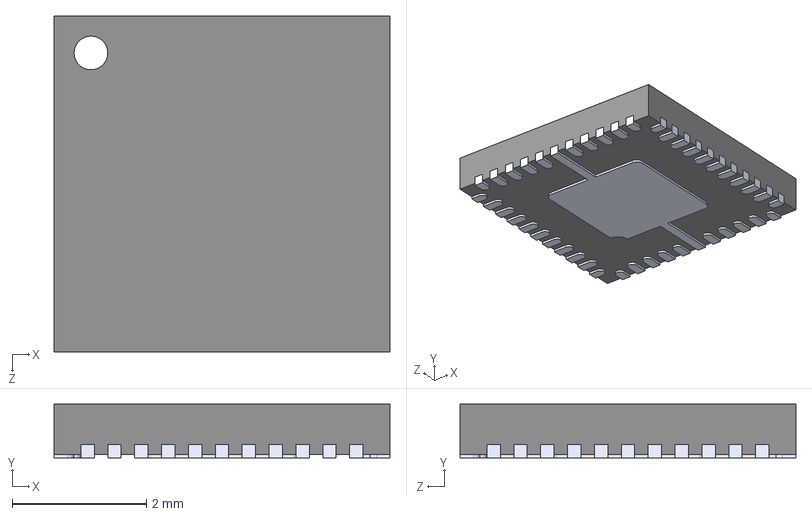
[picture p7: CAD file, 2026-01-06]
hardware/bokaka/stepfiles/IS31FL3236A-QFLS2-TR--3DModel-STEP-56544.STEP
5.00 x 0.8 x 5.00 mm

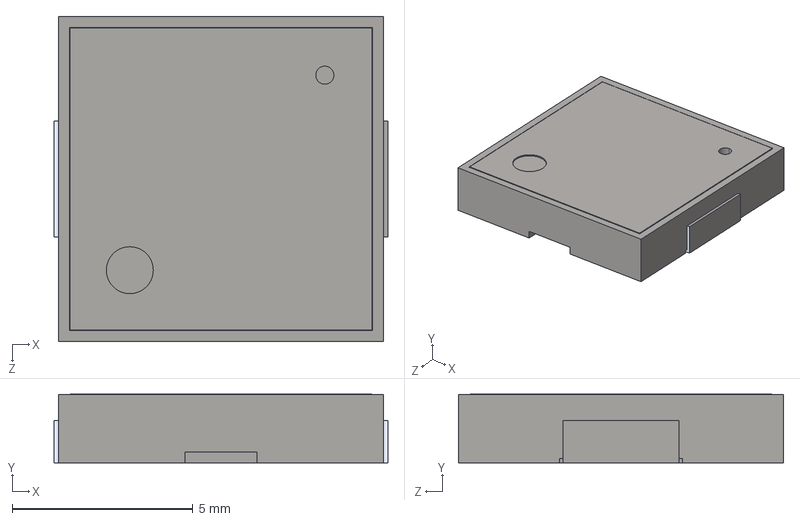
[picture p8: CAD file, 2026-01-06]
hardware/bokaka/stepfiles/CPT-9019S-SMT.step
9.24 x 1.91 x 9.00 mm

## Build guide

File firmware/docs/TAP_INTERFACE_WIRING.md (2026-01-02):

# Tap Interface Wiring Guide

## Overview

This document describes how to wire two Nucleo boards (or STM32L053R8-based boards) together to test the tap link interface. The tap link uses a 1-wire open-drain protocol for device-to-device communication.

---

## Required Components

- **2× Nucleo-L053R8 boards** (or compatible STM32L053R8 boards)
- **3× Jumper wires** (GND, 3.3V, and tap link signal)
- **2× USB cables** for power and USB CDC communication
- **Optional**: External LEDs (2× per board) for status indication

---

## Connection Diagram

```
Board A (Device 1)          Board B (Device 2)
┌─────────────────┐        ┌─────────────────┐
│                 │        │                 │
│  GND ───────────┼────────┼── GND          │
│                 │        │                 │
│  3.3V ──────────┼────────┼── 3.3V         │
│                 │        │                 │
│  PA9 (D8) ──────┼────────┼── PA9 (D8)      │
│  (Tap Link)     │        │  (Tap Link)     │
│                 │        │                 │
│  PA5 ────[LED]──┤        │  PA5 ────[LED]──┤
│  (Status LED0)  │        │  (Status LED0)  │
│                 │        │                 │
│  PA6 ────[LED]──┤        │  PA6 ────[LED]──┤
│  (Status LED1)  │        │  (Status LED1)  │
│                 │        │                 │
└─────────────────┘        └─────────────────┘
```

---

## Pin Assignments

| Function | Pin | Arduino Name | Notes |
|---|-----|---|---|
| **Tap Link** | PA9 | D8 | 1-wire open-drain, CN5 digital header |
| **Status LED 0** | PA5 | D13 | Readiness/handshake status |
| **Status LED 1** | PA6 | D12 | Master/Slave role indication |

---

## Wiring Instructions

### Step 1: Power Connections

⚠️ **Connect GND first, then power!**

1. **Ground (GND)**: Connect GND pins between both boards
2. **Power (3.3V)**: Connect 3.3V pins between both boards

### Step 2: Tap Link Signal

Connect **PA9 (D8)** on Board A to **PA9 (D8)** on Board B.

**How it works:**
- Both boards configure PA9 as **input with pull-up** when idle (line HIGH)
- When sending data, switch to **output LOW** (pulls line LOW)
- Open-drain allows both boards to drive LOW without conflict

### Step 3: Status LEDs (Optional)

```
PA5/PA6 ──[220Ω]──[LED]── GND
```

---

## Wiring Checklist

- [ ] **GND**: Board A GND → Board B GND
- [ ] **3.3V**: Board A 3.3V → Board B 3.3V  
- [ ] **PA9 (D8)**: Board A D8 → Board B D8 (Tap Link)
- [ ] **USB Power**: Connect USB cables to both boards

---

## Testing

### Power-On Test

1. Power on both boards
2. **LED 0** shows **Booting** pattern (120ms ON, 380ms OFF)
3. After boot, **LED 0** shows **Idle** pattern (120ms ON, 880ms OFF)

### Connection Test

1. Ensure both boards are in Idle state
2. Connect tap link wire (D8 to D8)
3. Observe LED patterns:
   - **LED 0**: Detecting → Negotiating → Success
   - **LED 1**: Master (ON) on one board, Slave (OFF) on other

### USB Serial Commands

| Command | Description |
|---|---|
| `hello` | Check device is responding |
| `get_state` | View connection count and links |
| `dump` | View stored peer IDs |

---

## Troubleshooting

### No Connection Detected

| Cause | Solution |
|---|---|
| Missing GND connection | Verify GND is connected between boards |
| Wrong pin | Verify PA9 (D8) is connected on both boards |
| Firmware not running | Check USB serial for boot messages |

### Connection Fails During Handshake

| Cause | Solution |
|---|---|
| Timing issues | Check wire connections, use shorter wires |
| Power issues | Verify adequate power supply |

### LEDs Not Working

| Cause | Solution |
|---|---|
| Wrong pins | Verify LED pin assignments |
| LED polarity | Anode to pin, cathode to GND |
| Missing resistor | Add 220Ω current limiting resistor |

---

## Pin Location Reference (Nucleo-L053R8)

```
CN5 (Digital Header - Right Side):
  ┌─────────┬─────────┐
  │  D8      │  D9     │  ← D8 (PA9) for tap link
  │  D10     │  D11    │
  │  D12     │  D13    │  ← D12 (PA6) LED 1, D13 (PA5) LED 0
  │  GND     │  AREF   │
  └─────────┴─────────┘

CN6 (Power Header - Left Side):
  ┌─────────┬─────────┐
  │  3.3V   │  GND    │  ← Use this 3.3V and GND
  └─────────┴─────────┘
```

---

## See Also

- [STATUS_DISPLAY.md](STATUS_DISPLAY.md) - LED pattern documentation
- [TAP_LINK_TIMING.md](TAP_LINK_TIMING.md) - Protocol timing details

---

*Last Updated: January 2026*

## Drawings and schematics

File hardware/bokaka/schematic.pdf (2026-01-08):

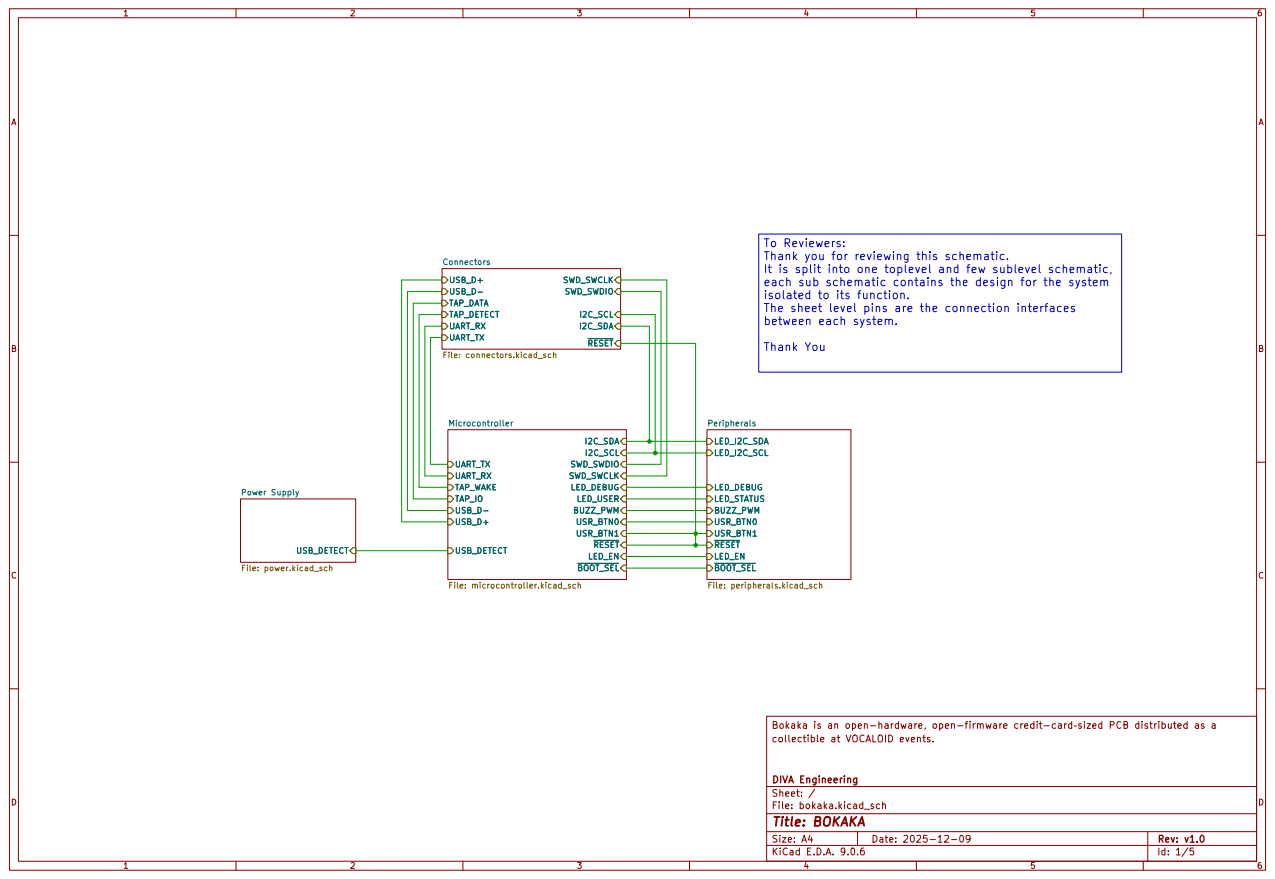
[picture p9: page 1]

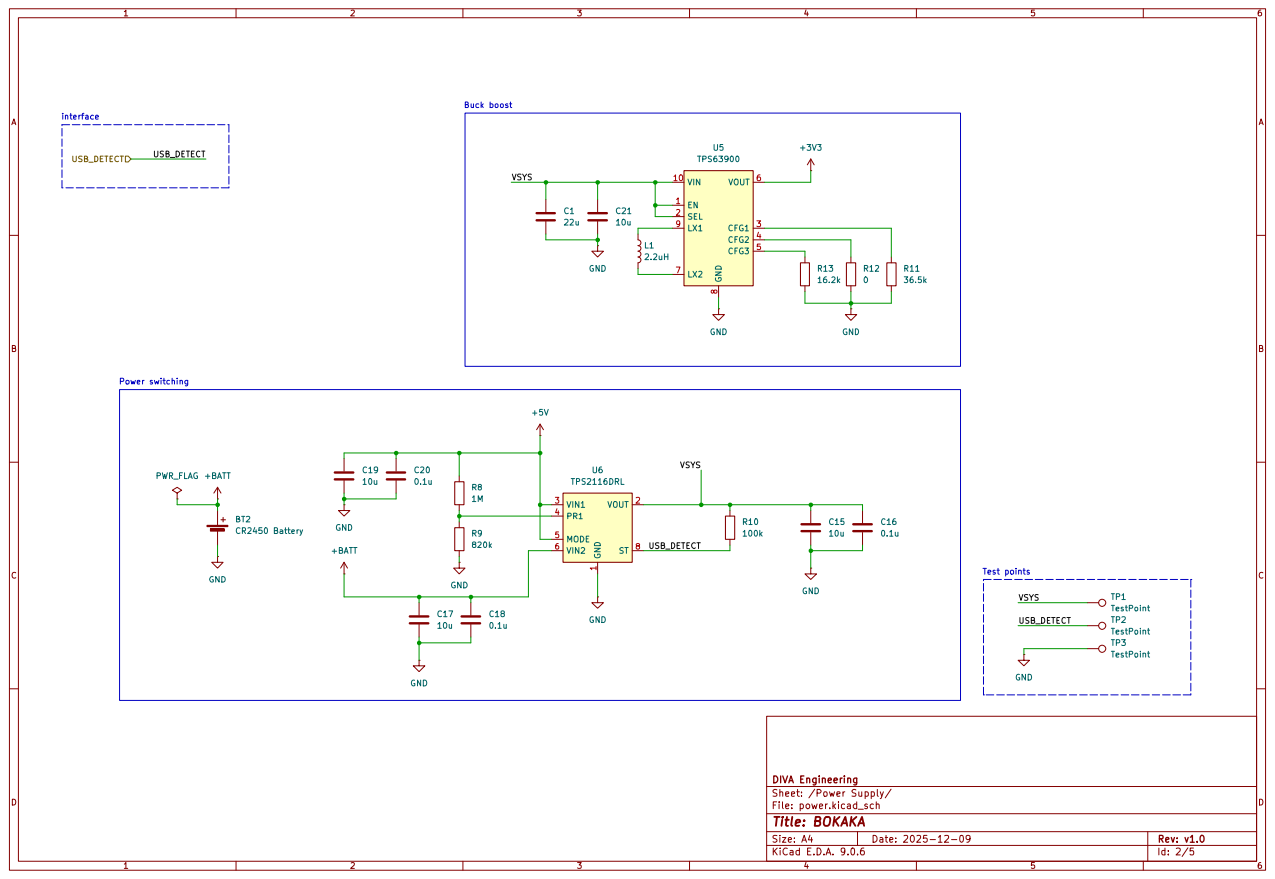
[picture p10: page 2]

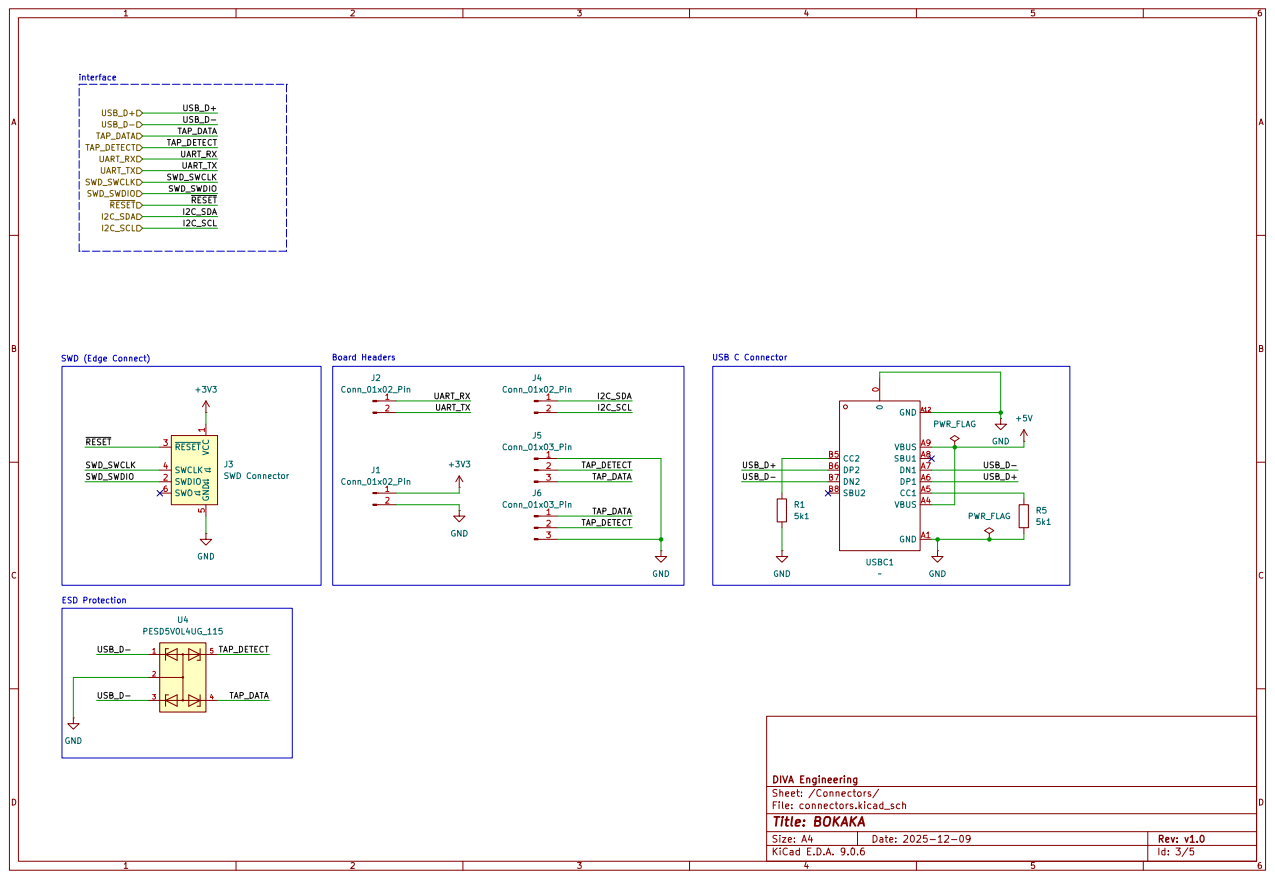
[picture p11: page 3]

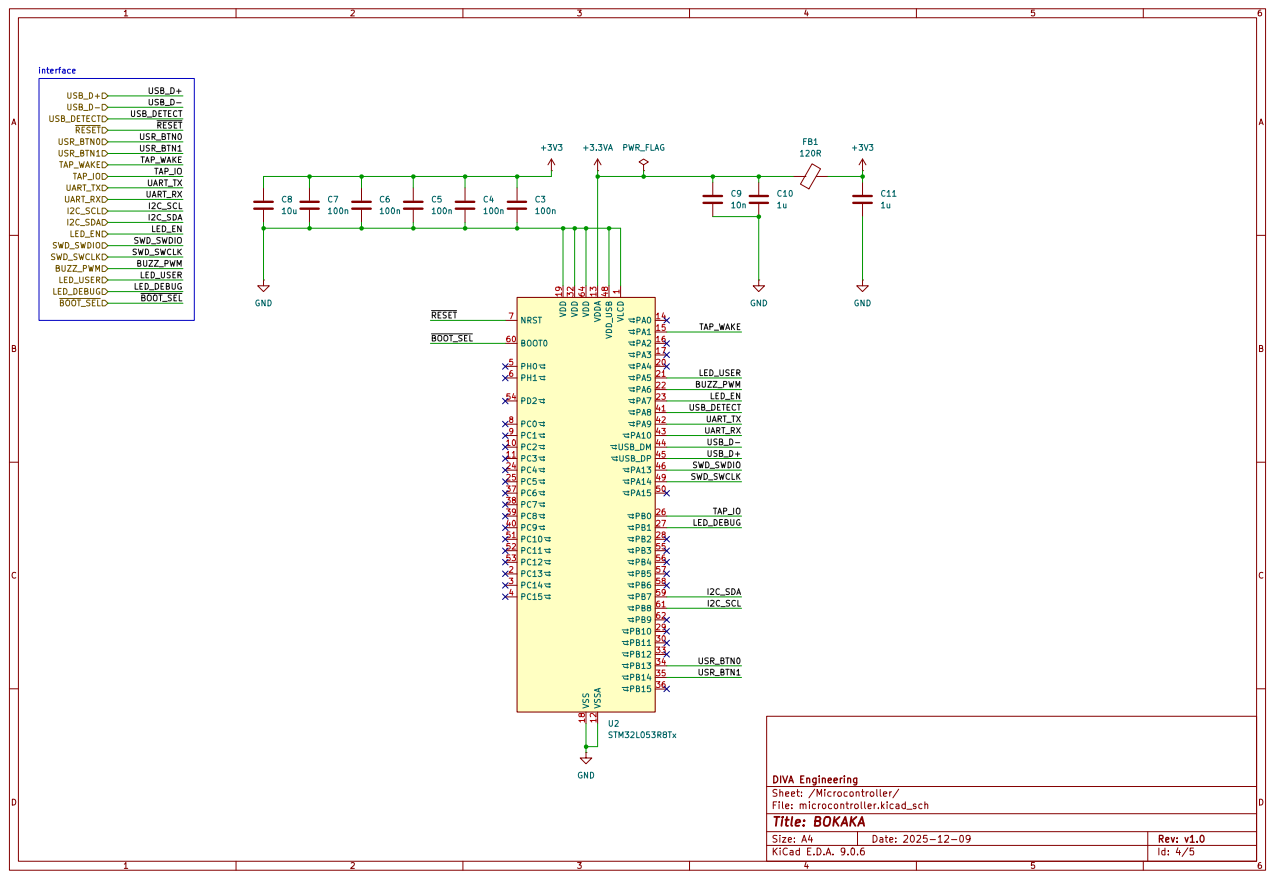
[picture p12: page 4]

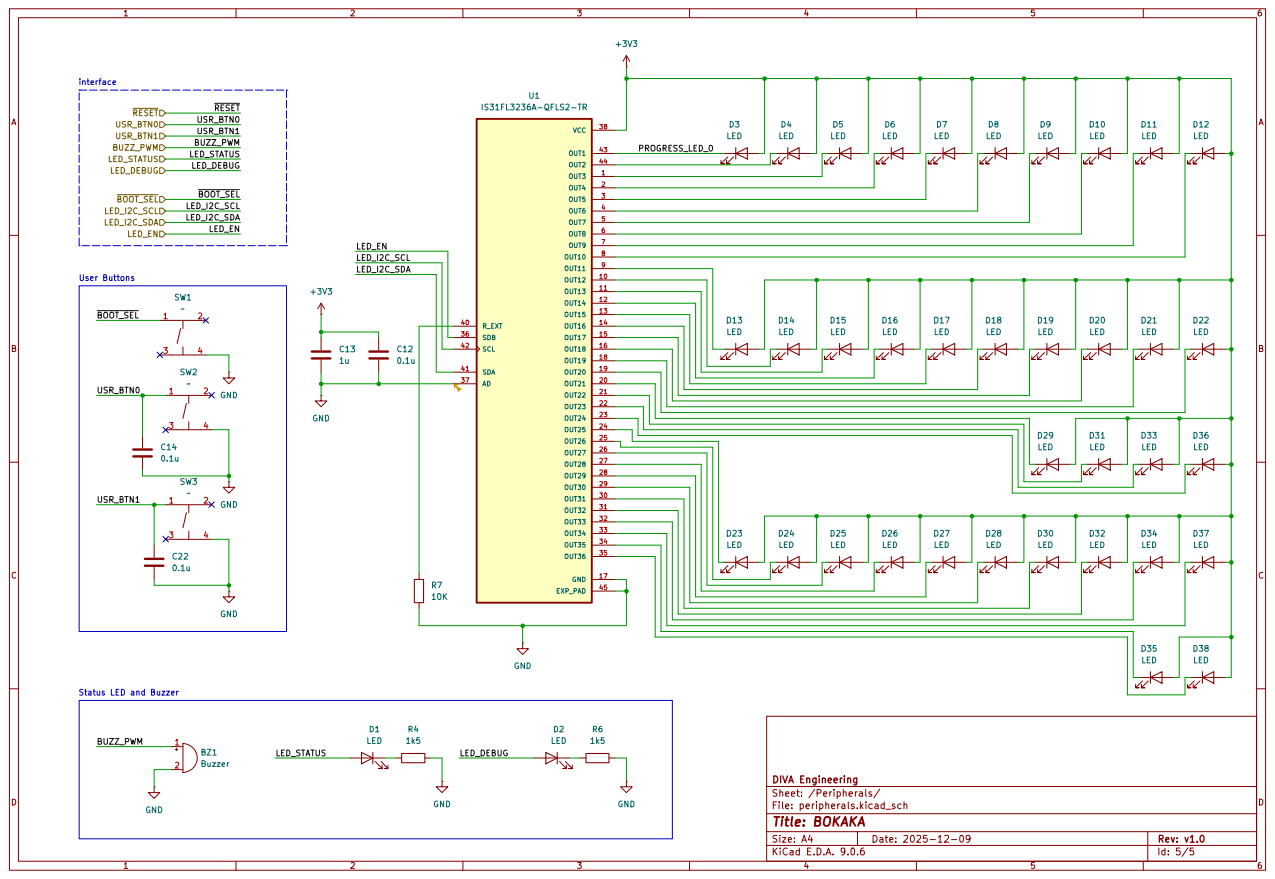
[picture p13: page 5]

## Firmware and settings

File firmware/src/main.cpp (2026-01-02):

// =====================================================
// Main Entry Point
// =====================================================
// Minimal Arduino entry point that delegates to Application class.
// All business logic is encapsulated in Application for testability.
// =====================================================

#include "board_config.h"  // Includes Arduino.h for setup/loop signatures
#include "application.h"

// Single global Application instance
static Application gApp;

void setup() {
    gApp.init();
}

void loop() {
    gApp.loop();
}

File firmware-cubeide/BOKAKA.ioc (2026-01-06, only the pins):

Mcu.UserName=STM32L053R8Tx
PA1.GPIO_Label=TAP_WAKE
PA1.Signal=GPXTI1
PA10.Signal=USART1_RX
PA11.Signal=USB_DM
PA12.Signal=USB_DP
PA13.Signal=SYS_SWDIO
PA14.Signal=SYS_SWCLK
PA5.GPIO_Label=USR_LED
PA5.Signal=GPIO_Output
PA6.GPIO_Label=BUZZ_PWM
PA6.Signal=S_TIM22_CH1
PA7.GPIO_Label=LED_EN
PA7.Signal=GPIO_Output
PA8.GPIO_Label=USB_DETECT
PA8.Signal=GPIO_Input
PA9.Signal=USART1_TX
PB0.GPIO_Label=TAP_IO
PB0.Signal=GPIO_Output
PB1.GPIO_Label=DEBUG_LED
PB1.Signal=GPIO_Output
PB13.GPIO_Label=USR_BTN0
PB13.Signal=GPIO_Input
PB14.GPIO_Label=USR_BTN1
PB14.Signal=GPIO_Input
PB6.Signal=I2C1_SCL
PB7.Signal=I2C1_SDA

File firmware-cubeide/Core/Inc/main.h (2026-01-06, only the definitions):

#define TAP_WAKE_Pin GPIO_PIN_1
#define TAP_WAKE_GPIO_Port GPIOA
#define USR_LED_Pin GPIO_PIN_5
#define USR_LED_GPIO_Port GPIOA
#define BUZZ_PWM_Pin GPIO_PIN_6
#define BUZZ_PWM_GPIO_Port GPIOA
#define LED_EN_Pin GPIO_PIN_7
#define LED_EN_GPIO_Port GPIOA
#define TAP_IO_Pin GPIO_PIN_0
#define TAP_IO_GPIO_Port GPIOB
#define DEBUG_LED_Pin GPIO_PIN_1
#define DEBUG_LED_GPIO_Port GPIOB
#define USR_BTN0_Pin GPIO_PIN_13
#define USR_BTN0_GPIO_Port GPIOB
#define USR_BTN1_Pin GPIO_PIN_14
#define USR_BTN1_GPIO_Port GPIOB
#define USB_DETECT_Pin GPIO_PIN_8
#define USB_DETECT_GPIO_Port GPIOA

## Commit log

2025-12-08 adding firmware tap HAL and pcb project
    [bokaka.kicad_pcb, bokaka.kicad_sch]
2025-12-11 Adding power and connector
    [bokaka.kicad_sch, connectors.kicad_sch, microcontroller.kicad_sch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]
2025-12-12 Adding rest of design and pdf
    [bokaka.kicad_sch, connectors.kicad_sch, microcontroller.kicad_sch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]
2025-12-20 Updating to include the tap link HAL implementation
    [microcontroller.kicad_sch]
2026-01-06 Finalize design before pcb
    [CPT-9019S-SMT.step, IS31FL3236A-QFLS2-TR--3DModel-STEP-56544.STEP, SW-SMD_4P-L5.1-W5.1-P3.70-LS6.5-TL_H1.5.step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]
2026-01-07 footprint asignment
    [USB-C-SMD_TYPE-C-USB-17.step, bokaka.kicad_sch, connectors.kicad_sch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]
2026-01-08 schematic update
    [bokaka.kicad_sch, connectors.kicad_sch, microcontroller.kicad_sch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]
2026-01-10 hardware update
    [bokaka.kicad_sch, microcontroller.kicad_sch, peripherals.kicad_sch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]
2026-01-29 Devkit Production Ready
    [BOM-bokaka.csv, BUZ-SMD_4P-L8.5-W8.5-H3.0.step, PESD5V0L4UG,115.STEP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]

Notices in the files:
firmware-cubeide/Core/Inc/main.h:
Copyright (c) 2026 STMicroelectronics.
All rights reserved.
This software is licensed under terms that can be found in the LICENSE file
